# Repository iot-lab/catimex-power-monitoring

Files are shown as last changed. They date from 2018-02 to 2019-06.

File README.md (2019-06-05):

# Catimex: Hardware

Custom developer board for measure the power consumption of a load connected in either the USB connector or in the HOUT header connector.

## Overview
This folder contains the necessary files to replicate the custom board develop for catimex project. This board has the following features:
* [STM32F103RE Microcontroller](https://www.st.com/en/microcontrollers/stm32f103re.html)
* [FT2232H USB Bridge](https://www.ftdichip.com/Support/Documents/DataSheets/ICs/DS_FT2232H.pdf)
* [INA226 Power monitor](http://www.ti.com/product/INA226)

The board has two different power supply, one for the load (open-node) and other for the main microcontroller (control-node). In the picture below, the micro usb connector of the open node is marked in blue, while the connector for the control node is marked in a red rectangle.

In this version the jumper in 3V3 must be placed to power the control node.

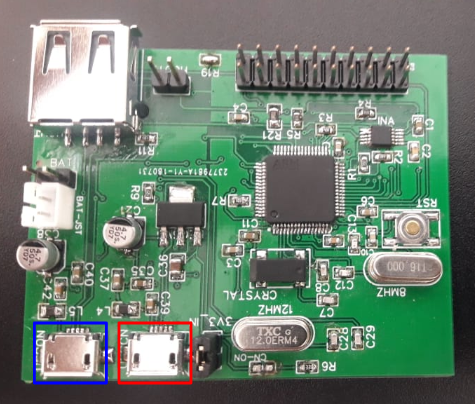
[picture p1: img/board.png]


## How to use

### Power the board
#### From a usb port
To measure the power consumption of any load, connect two micro usb ports to each connector. The control node will send the information through serial port so you need to connect this to a pc. On the other side you can power the open node from a pc usb port or any other source.

#### From an external source
If you do not want to connect the control node to a pc, you can connect a battery in the JST connector on the board and access to serial port through the pin headers exposed on the board.

### Connect the load
The load or open-node should be connected in the usb connector or in the HOUT header connector. Once plug in you should start to receive the measurement of bus voltage and current used by the board.

### Power Supply and Start-up Considerations
The board available connectors are:
* USBCN : USB connector for the control node. If connected the control node is power up and you will be able to receive through serial console.
* USBON : USB connector for power up and interact with any node connected, in this case the open node.
* USB : USB port to connect a external node, as in this case the open node
* HOUT : Header to power an external node (open node) from a header connector instead of using the USB port above.
* BAT : Header connector to plug any external battery for the open node, instead of use USBON connection.
* BAT-JST : JST connector to plug in an external battery
* 3V3_IN : Feed the control node from the on-board voltage regulator and USBCN. A jumper has to be connecting both pins in order to power the control node from USB port. Note: This was build for development purposes.

The pinout configuration is in the image below:

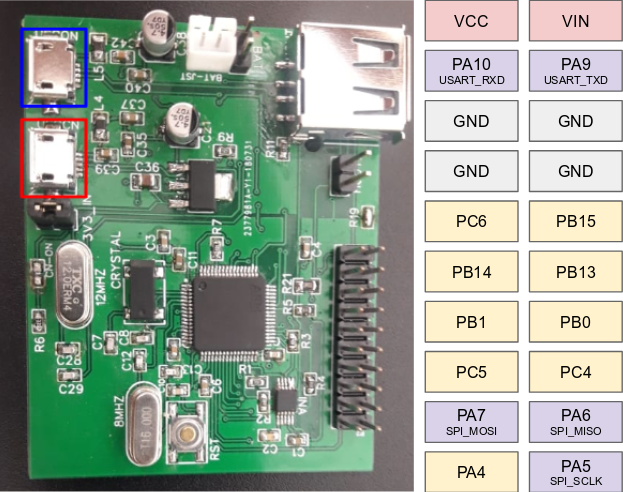
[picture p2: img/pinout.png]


## Need features
From the different test made, there are the following missing features:
* Add 2 LEDs to the board
* Add an OFF state for power the open node
* Match I2C port for INA226 with current in FIT IoTLab and the ALERT interrupt pin
* Add a battery charger
* Be able to put a 802.15.4 radio on top
* Expose same pins as the control node in FIT
* Be able to measure voltage of battery

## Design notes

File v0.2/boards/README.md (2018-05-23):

# PCB eagle for current measurement board

This folder contains the eagle files for v0.2 current measurement board. It contains two options for the circuit:

* LTC6102 based circuit measurement
* ADA4522 based circuit measurement

This version only contains the circuit for measure the current, does not have a mcu inside or any control for the usb hub. It has different pins and test pads to access and control the behavior of the board, as the calibration stage, the output of the stages, the power management among others.

## Input and Outputs
The inputs of this version of the board control different areas which can be access through:
 * Micro usb port
 * Pins for optional external power
 * Pin SW_PWR for selecting source of power for the target MCU
 * Pins SW0-SW4 to control calibration

The output depends of the specific version of the board, but in general terms it contains:
 * Pins to access to the measurement value
 * USB port to connect target MCU  

## How to Use
For use this board you need a external mcu that can read the adc value from the output and can control the different input of the system

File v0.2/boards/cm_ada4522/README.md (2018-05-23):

# Current measurement board based on ADA4522

This version of the measurement board uses an ADA4522 opamp. This opamp was chosen for its CMRR, Low voltage drift, low offset voltage and other characteristics for this application. It was used in an instrumentation amplifier configuration.

The circuit is divided in two types of currents ranges, the in amp configuration is design to measure the range 1uA - 1mA, the other one use the AD8422 precision instrumentation amplifier for the range 1mA-100mA.

### Rating
 * Low current range 1st stage gain x100
 * Low current range 2st stage gain x10
 * High current range gain x40

#### Input and Outputs
The inputs of board are:
 * Micro usb port
 * Pins for optional external power
 * Pin SW_PWR for selecting source of power for the target MCU
 * Pins SW0-SW4 to control calibration

The outputs:
 * Pins to access to both the measurement value: VoutL, VoutH, GND
 * USB port to connect target MCU  

#### Jumpers
Different jumpers are used in the board to select connect internal or external power to feed the IC.

#### Test Pads
At least three test pads were put in the board to can measure key values, as in the first stage output, output of power stages and output of regulation stage.

## Board versions
### ADA4522 v0
This version of the board is being develop and tested

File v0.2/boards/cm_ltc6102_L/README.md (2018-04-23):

# PCB eagle for LTC6102 based current measurement board

### Some notation
* current measuring board (CMB): the designed circuit that measure shunt voltage, and supply voltage.
* mcu: the microcontroller that is connect to the CMB, performs calibrations and converts the supply voltage and current measurements.
* node: the target mcu which pwoer consumption the CMB is measuring.

### How to use

* connect switch controllers (SW0 to SW4) to 5 different GPIO on any mcu.
* if you wan't to control what supply is used for the node connect SW_PWR
* connect the ADC_CM_LOW to and ADC pin on your mcu
* connect INA226 sda and scl to your mcu sda and scl pins, PU ressitors are supplied in this board
* alert pin of INA226 is supplied, not used by default
* power the CMB by either connecting it to it's microUSB port ore the 5V supply pin.
* bypass the targeted node power supply by either connecting it's power source to VEXT or the USB port on CMB.
* if the targeted node supply source is connected to VEXT then the node can be powered by connecting it's power input to VMCU. By default the mcu will be supplied from the USB. SW_CTRL_PWR allows the user to select which.

### Ratings:
- Power supply: 5V from USB or 5V from external supply
- First Low range stage gain x1000.
- Second Low range stage gain x11.
- Ina226 for High current range 82mA-250uA
- LTC6102 for Low current range 250ua-0.01uA

#### Input Output pins

Multiple input/output pins are supplied (There are PD resistors so calibration resistors and node supply are normally turned off). These are:

- SW_PWR: switch between VEXT and VUSB for supplying node.
- SW0: switch between calibration mode and suplying node.
- SW1-4: switches on or off calibration resistors.
- VMCU: output voltage that powers the targeted node it's short-circuited to the female type A USB.
- GND: ground
- ADC: low current value tu be read by mcu ADC
- SDA/SCL: I2C wire connection to read INA226 voltage and current values
- VEXT: external supply oint for node, eg: a battery
- +5V: 5V input/output depending on operation

#### Jumper

- A jumpers enables or not the use of the regulated 5V power supply, if not the filtered USB supply powers all the CMB IC's

#### Test Pads

Multiple test pads have been exposed for board testing

- 5V_F: filter 5V usb supply
- 5.5V: output of boost stage
- 5VR: 5 vols LDO output
- Vin: voltage that comes in to 4-terminal shunt current in pad
- Vout: voltage that comes out of 4-terminal shunt current out pad
- SHUNT+: voltage that comes form 4-terminal shunt voltage+ read pad
- SHUNT-: voltage that comes form 4-terminal shunt voltage- read pad

#### Leds

The board has 6 status Leds:

- MCU_VUSB_LED: indicates if node is supplied from USB
- MCU_EXT_LED: indicates if node is supplied from external supply
- VCALID_LED: indicates if in calibration mode
- VMCU_LED: indicates if in normal mode
- USB_LED: if usb is connected
- 5V_LED: if regultor is on

# Board versions

## LTC6102 v0

### Details

Analog and digital ground are joined in star way.

USB supply is filterd threw a ferrite, every precisión IC is also isolated threw a ferrite.

USB enclosure is connected to the digital ground.

### Prototyping and testing conclusion

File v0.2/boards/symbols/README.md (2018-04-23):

## This folder contains all eagle symbols used in the board.

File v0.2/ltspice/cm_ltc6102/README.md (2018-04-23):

# Spice models for power measurement boards
These spice models were used to simulate the behavior of the circuits before prototyping them. 

## About files
### cm_ad4522_A.asc
Simulates a ADA4522 based circuit. Three of them are connectd as an INA and a forth as a Salen Key filter. Was not prototyped.

### cm_ltc6102
Simulates a LTC6102 based circuit. Uses LTC6102 as first stage, it is operating out of data sheet range but still with inputs as low as 2.7V. It has a gain of x1000.

#### A v/s B
A v/s B version changes the type of low pass filter used at the output. In one case it's Salen Key 2nd order (A) and in the other a simple RC filter (B).

#### tlv272 v/S ADA4528
This deffines two ways of implementing the second gain stage and sallen-key filter (when there is one)
. Both have similar operations at different costs.

### v3_max4239_lt624X.asc
This schematic was used to simulated and verify the sallen key designed cut-off frequency and operation.

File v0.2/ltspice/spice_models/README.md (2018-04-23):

## SPICE MODELS

This folder contains spice models for the IC used in the Ltspice schematics.

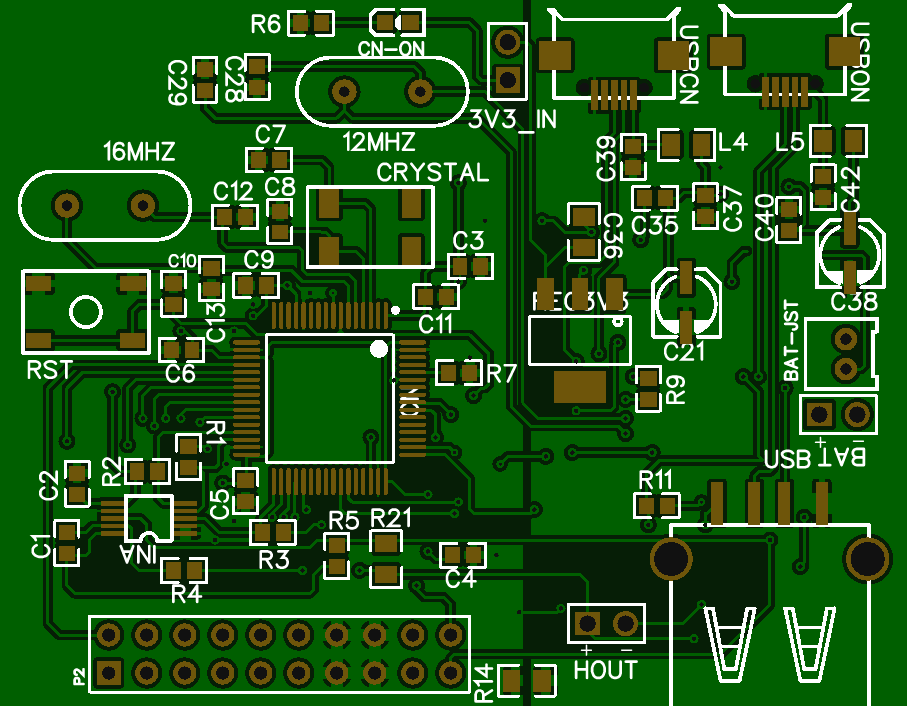
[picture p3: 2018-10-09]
Layout/top.png

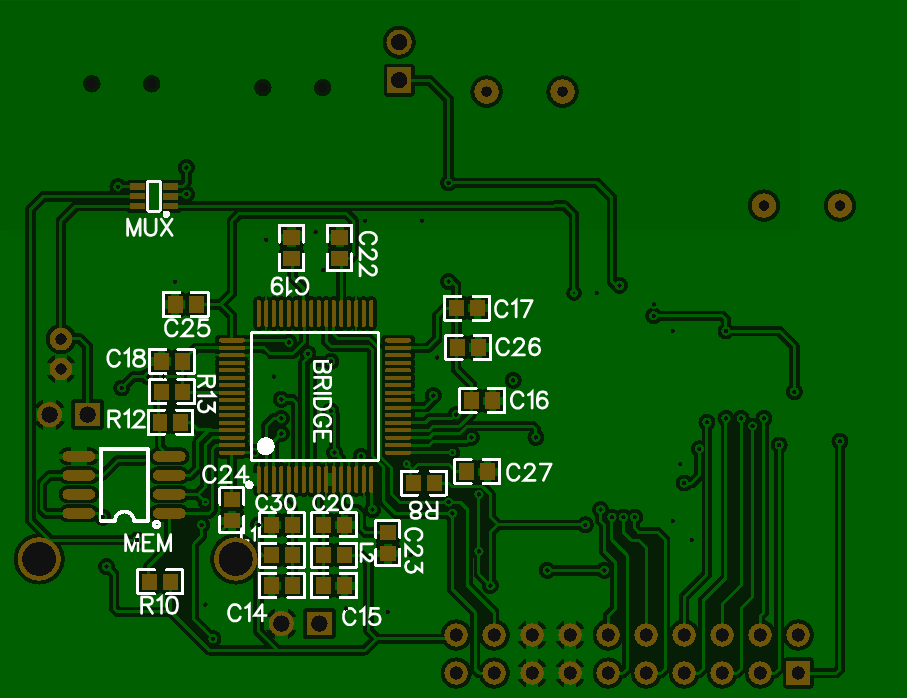
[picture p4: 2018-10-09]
Layout/bottom.png

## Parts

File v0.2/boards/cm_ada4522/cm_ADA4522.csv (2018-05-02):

Index | Quantity | Part Number | Description | Customer Reference | Available Quantity | Backorder Quantity | Unit Price USD | Extended Price USD
1 | 1 | RG16N100WCT-ND | RES SMD 100 OHM 0.05% 1/10W 0603 |  | 1 | 0 | 0.92 | 0.92
2 | 5 | TNP100KAACT-ND | RES 100K OHM 0.1% 1/8W 0603 |  | 5 | 0 | 0.462 | 2.31
3 | 2 | RG16N510WCT-ND | RES SMD 510 OHM 0.05% 1/10W 0603 |  | 2 | 0 | 0.92 | 1.84
4 | 2 | RG16N20.0KWCT-ND | RES SMD 20K OHM 0.05% 1/10W 0603 |  | 2 | 0 | 0.92 | 1.84
5 | 2 | RG16P200BCT-ND | RES SMD 200 OHM 0.1% 1/10W 0603 |  | 2 | 0 | 0.41 | 0.82
6 | 1 | AD8422BRMZ-ND | IC OPAMP INSTR 2.2MHZ RRO 8MSOP |  | 1 | 0 | 8.68 | 8.68
7 | 1 | ADM7170ACPZ-3.0-R7CT-ND | IC REG LINEAR 3V 500MA 8LFCSP |  | 1 | 0 | 2.7 | 2.7
8 | 1 | LT8582EDKD#PBF-ND | IC REG MULT CONFIG INV ADJ 24DFN |  | 1 | 0 | 8.18 | 8.18
9 | 1 | 576-3967-1-ND | IC REG BOOST ADJ 0.9A SOT23-5 |  | 1 | 0 | 0.73 | 0.73
10 | 3 | 497-5561-1-ND | DIODE SCHOTTKY 40V 300MA SOD523 |  | 3 | 0 | 0.36 | 1.08
11 | 2 | 160-1447-6-ND | LED RED CLEAR 0603 SMD |  | 2 | 0 | 3.79 | 7.58
12 | 2 | 160-1446-6-ND | LED GREEN CLEAR 0603 SMD |  | 2 | 0 | 3.79 | 7.58
13 | 2 | P12KDBCT-ND | RES SMD 12K OHM 0.1% 1/10W 0603 |  | 2 | 0 | 0.35 | 0.7
14 | 1 | P143KDBCT-ND | RES SMD 143K OHM 0.1% 1/10W 0603 |  | 1 | 0 | 0.35 | 0.35
15 | 1 | P130KDBCT-ND | RES SMD 130K OHM 0.1% 1/10W 0603 |  | 1 | 0 | 0.35 | 0.35
16 | 1 | Y1606-1.0B-ND | RES SMD 1 OHM 1W 2516 WIDE |  | 1 | 0 | 16.56 | 16.56
17 | 2 | A103067CT-ND | RES SMD 22 OHM 0.1% 1/16W 0603 |  | 2 | 0 | 0.55 | 1.1
18 | 1 | P2.0KDBCT-ND | RES SMD 2K OHM 0.1% 1/10W 0603 |  | 1 | 0 | 0.35 | 0.35
19 | 1 | P10KDBCT-ND | RES SMD 10K OHM 0.1% 1/10W 0603 |  | 1 | 0 | 0.35 | 0.35
20 | 1 | P30KDBCT-ND | RES SMD 30K OHM 0.1% 1/10W 0603 |  | 1 | 0 | 0.35 | 0.35
21 | 2 | P53.6KDBCT-ND | RES SMD 53.6KOHM 0.1% 1/10W 0603 |  | 2 | 0 | 0.35 | 0.7
22 | 1 | P6.04KDBCT-ND | RES SMD 6.04KOHM 0.1% 1/10W 0603 |  | 1 | 0 | 0.35 | 0.35
23 | 1 | A102234CT-ND | RES SMD 1M OHM 0.1% 1/16W 0603 |  | 1 | 0 | 0.44 | 0.44
24 | 1 | 541-10MAYCT-ND | RES SMD 10M OHM 0.5% 1/10W 0603 |  | 0 | 1 | 0.31 | 0.31
25 | 2 | 490-4780-1-ND | CAP CER 1000PF 100V X7R 0603 |  | 2 | 0 | 0.1 | 0.2
26 | 2 | 490-1458-1-ND | CAP CER 2000PF 50V C0G/NP0 0603 |  | 2 | 0 | 0.17 | 0.34
27 | 1 | 490-4781-1-ND | CAP CER 10000PF 100V X7R 0603 |  | 1 | 0 | 0.1 | 0.1
28 | 5 | 445-9871-1-ND | CAP CER 0.1UF 25V X8R 0603 |  | 5 | 0 | 0.28 | 1.4
29 | 2 | 587-4958-1-ND | CAP CER 1UF 50V X5R 0603 |  | 2 | 0 | 0.3 | 0.6
30 | 5 | 445-9015-1-ND | CAP CER 10UF 25V X5R 0603 |  | 0 | 5 | 0.96 | 4.8
31 | 5 | 1276-1900-1-ND | CAP CER 4.7UF 25V X5R 0603 |  | 5 | 0 | 0.43 | 2.15
32 | 2 | 1276-1878-1-ND | CAP CER 2.2UF 25V X5R 0603 |  | 2 | 0 | 0.29 | 0.58
33 | 1 | 296-19265-1-ND | IC SWITCH SPDT SOT23-6 |  | 1 | 0 | 0.88 | 0.88
34 | 1 | 296-19804-1-ND | IC SWITCH SPDT SC70-6 |  | 1 | 0 | 0.61 | 0.61
35 | 1 | 296-17906-1-ND | IC SWITCH DUAL SPST US8 |  | 1 | 0 | 0.84 | 0.84
36 | 1 | NDS8434CT-ND | MOSFET P-CH 20V 6.5A 8-SOIC |  | 1 | 0 | 1.82 | 1.82
37 | 5 | 732-2956-1-ND | FIXED IND 4.7UH 1A 160 MOHM SMD |  | 5 | 0 | 0.81 | 4.05
38 | 1 | 609-4618-1-ND | CONN USB MICRO B RECPT SMT R/A |  | 1 | 0 | 0.42 | 0.42
39 | 1 | ADA4522-4ARUZ-ND | IC OPAMP 55V LN ZD 14TSSOP |  | 1 | 0 | 8.53 | 8.53
40 | 8 | YAG1237CT-ND | RES SMD 1K OHM 0.1% 1/10W 0603 |  | 8 | 0 | 0.34 | 2.72
41 | 1 | 490-1058-1-ND | FERRITE BEAD 60 OHM 1806 1LN |  | 1 | 0 | 0.32 | 0.32
42 | 10 | 1276-3486-1-ND | RES 100K OHM 1% 1/8W 0603 |  |  |  | 0.1 | 0.33

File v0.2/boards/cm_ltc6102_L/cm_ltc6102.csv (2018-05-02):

Index | Quantity | Part Number | Description | Customer Reference | Available Quantity | Backorder Quantity | Unit Price USD | Extended Price USD
1 | 5 | RNCF0603TKY10K0CT-ND | RES 10K OHM 0.01% 1/10W 0603 |  | 5 | 0 | 2.15000 | 10.75
2 | 1 | ADA4528-2ARMZ-R7CT-ND | IC OPAMP ZERO-DRIFT 3.4MHZ 8MSOP |  | 1 | 0 | 4.74000 | 4.74
3 | 2 | A124686CT-ND | RES SMD 9.09 OHM 0.1% 1/16W 0603 |  | 2 | 0 | 0.78000 | 1.56
4 | 1 | RNCF0805TKY1K00CT-ND | RES 1K OHM 0.01% 1/8W 0805 |  | 1 | 0 | 2.15000 | 2.15
5 | 1 | Y1607-1.00-ND | RES SMD 1 OHM 1/2W 2516 WIDE |  | 1 | 0 | 12.30000 | 12.30
6 | 1 | 490-12558-1-ND | CAP CER 0.1UF 16V X7R 0805 |  | 1 | 0 | 0.12000 | 0.12
7 | 2 | RNCF0603AKT10R0CT-ND | RES 10 OHM 0.05% 1/10W 0603 |  | 2 | 0 | 0.97000 | 1.94
8 | 1 | A103123CT-ND | RES SMD 6.2K OHM 0.1% 1/16W 0603 |  | 1 | 0 | 0.68000 | 0.68
9 | 1 | 399-13711-1-ND | CAP CER 0603 10PF 50V X7R 10% AU |  | 1 | 0 | 0.26000 | 0.26
10 | 3 | 490-1047-1-ND | FERRITE BEAD 1 KOHM 0805 1LN |  | 3 | 0 | 0.17000 | 0.51
11 | 5 | 490-1543-1-ND | CAP CER 1UF 10V X5R 0603 |  | 5 | 0 | 0.12000 | 0.60
12 | 1 | 490-1058-1-ND | FERRITE BEAD 60 OHM 1806 1LN |  | 1 | 0 | 0.32000 | 0.32
13 | 1 | ADM7170ACPZ-5.0-R7CT-ND | IC REG LINEAR 500MA 8LFCSP |  | 0 | 1 | 2.70000 | 2.70
14 | 3 | 490-6065-1-ND | CAP CER 4.7UF 16V X7R 1206 |  | 0 | 3 | 0.58000 | 1.74
15 | 1 | 576-3967-1-ND | IC REG BOOST ADJ 0.9A SOT23-5 |  | 1 | 0 | 0.73000 | 0.73
16 | 1 | 490-11996-1-ND | CAP CER 2.2UF 10V X7R 0603 |  | 1 | 0 | 0.45000 | 0.45
17 | 1 | 497-5561-1-ND | DIODE SCHOTTKY 40V 300MA SOD523 |  | 1 | 0 | 0.36000 | 0.36
18 | 2 | 490-4774-1-ND | CAP CER 0.1UF 16V X7R 0603 |  | 0 | 2 | 0.10000 | 0.20
19 | 1 | 296-19265-1-ND | IC SWITCH SPDT SOT23-6 |  | 1 | 0 | 0.88000 | 0.88
20 | 4 | MCT0603-10.0K-CFCT-ND | RES SMD 10K OHM 1% 1/8W 0603 |  | 4 | 0 | 0.18000 | 0.72
21 | 1 | 311-1.00MHRCT-ND | RES SMD 1M OHM 1% 1/10W 0603 |  | 1 | 0 | 0.10000 | 0.10
22 | 1 | MCT0603-10.0M-CFCT-ND | RES SMD 10M OHM 1% 1/8W 0603 |  | 1 | 0 | 0.27000 | 0.27
23 | 1 | 160-1447-1-ND | LED RED CLEAR 0603 SMD |  | 1 | 0 | 0.29000 | 0.29
24 | 1 | 160-1446-1-ND | LED GREEN CLEAR 0603 SMD |  | 1 | 0 | 0.29000 | 0.29
25 | 2 | 160-1445-1-ND | LED ORANGE CLEAR 0603 SMD |  | 2 | 0 | 0.27000 | 0.54
26 | 1 | 609-4618-1-ND | CONN USB MICRO B RECPT SMT R/A |  | 1 | 0 | 0.42000 | 0.42
27 | 1 | 296-19804-1-ND | IC SWITCH SPDT SC70-6 |  | 1 | 0 | 0.61000 | 0.61
28 | 1 | 490-10563-1-ND | FIXED IND 10UH 1A 460 MOHM SMD |  | 1 | 0 | 0.22000 | 0.22
29 | 1 | 160-1448-1-ND | LED YELLOW CLEAR 0603 SMD |  | 1 | 0 | 0.31000 | 0.31
30 | 2 | 296-17906-1-ND | IC SWITCH DUAL SPST US8 |  | 2 | 0 | 0.84000 | 1.68
31 | 1 | 296-29034-1-ND | IC MONITOR PWR/CURR BIDIR 10MSOP |  | 1 | 0 | 2.88000 | 2.88
32 | 7 | 490-1494-1-ND | CAP CER 1000PF 50V X7R 0603 |  | 7 | 0 | 0.10000 | 0.70
33 | 6 | 311-1.00KHRCT-ND | RES SMD 1K OHM 1% 1/10W 0603 |  | 6 | 0 | 0.10000 | 0.60
34 | 8 | 311-100KHRCT-ND | RES SMD 100K OHM 1% 1/10W 0603 |  | 8 | 0 | 0.10000 | 0.80
35 | 1 | P100KBSCT-ND | RES SMD 100K OHM 0.05% 1/8W 0805 |  | 1 | 0 | 0.79000 | 0.79
36 | 3 | 541-3956-1-ND | RES SMD 1 OHM 1% 1/10W 0603 |  | 3 | 0 | 0.10000 | 0.30
37 | 1 | 541-0.0SBCT-ND | RES SMD 0 OHM JUMPER 1/4W 0603 |  | 1 | 0 | 0.17000 | 0.17
38 | 1 | 490-4781-1-ND | CAP CER 10000PF 100V X7R 0603 |  | 1 | 0 | 0.10000 | 0.10
39 | 1 | P29.4KDACT-ND | RES SMD 29.4K OHM 0.1% 1/8W 0805 |  | 1 | 0 | 0.36000 | 0.36
40 | 2 | 490-12380-1-ND | CAP CER 10UF 16V X5R 0805 |  | 2 | 0 | 0.34000 | 0.68
41 | 1 | LTC6102IMS8#PBF-ND | IC OPAMP CURR SENSE 200KHZ 8MSOP |  | 1 | 0 | 4.07000 | 4.07

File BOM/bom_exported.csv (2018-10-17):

ID | Name | Designator | Footprint | Quantity | Manufacturer Part | Manufacturer | Supplier | Supplier Part | Price | Mounted | LCSC Assembly
1 | INA226AIDGSR | INA | MSOP-10 | 1 | INA226AIDGSR | TI | Digi-Key | 296-29034-1-ND |  | Yes
2 | 3.3k 5% | R1,R2 | 0603 | 2 | ? |  | Digi-Key | 311-3.3KGRCT-ND |  | Yes
3 | 100k 5% | R3 | 0603 | 1 | ? |  | Digi-Key | P100KGCT-ND |  | Yes
4 | 10 1% | R4,R5 | 0603 | 2 | ? |  | Digi-Key | MCT0603-1.00-CFCT-ND |  | Yes
5 | 100n | C1,C2,C14,C15,C16,C17,C18,C19,C22,C23,C24,C26,C27,C3,C4,C5,C6,C10,C37,C40 | 0603 | 20 | ? |  | Digi-Key | 399-1099-1-ND |  | Yes
6 | 1 0.25% | R21 | 0805 | 1 | ? |  | Digi-Key | CRT0805-CY-1R00ELFCT-ND |  | Yes
7 | FT2232HL | BRIDGE | LQFP-64_10X10X05P | 1 | FT2232HL | FTDI | Digi-Key | 768-1024-1-ND |  | Yes
8 | 600R/0.5A | L1,L2 | 0603 | 2 | 742863160 |  | Digi-Key | 732-2389-1-ND |  | Yes
9 | 1u | C25,C11 | 0603 | 2 | ? |  | Digi-Key | 1276-1182-1-ND |  | Yes
10 | 10k | R8,R10,R11,R13,R7 | 0603 | 5 | ? |  | Digi-Key | P10KGCT-ND |  | Yes
11 | 12k | R9 | 0603 | 1 | ? |  | Digi-Key | P12KGCT-ND |  | Yes
12 | CRYSTAL | 12MHZ | HC49US | 1 | 9B-12.000MEEJ-B |  | Digi-Key | 887-1238-ND |  | No
13 | 27p | C28,C29 | 0603 | 2 | ? |  | Digi-Key | 490-6047-1-ND |  | Yes
14 | AT93C66B-SSHM-T | MEM | SOIC-8_150MIL | 1 | AT93C66B-SSHM-T | MICROCHIP | Digi-Key | AT93C66B-SSHM-TCT-ND |  | Yes
15 | 2.2k | R12 | 0603 | 1 | ? |  | Digi-Key | P2.2KGCT-ND |  | Yes
16 | 4.7u | C30,C20 | 0603 | 2 | ? |  | Digi-Key | 1276-1045-1-ND |  | Yes
17 | STM32F103RET6 | CN | LQFP-64_10X10X05P | 1 | STM32F103RET6 | STMicroelectronics | Digi-Key | 497-11529-ND |  | Yes | Yes
18 | ABS25 - Crystal 32.768kHz SMD | CRYSTAL | ABS25 - SMD CRYSTAL 32.768KHZ | 1 | ABS25-32.768KHZ-6-T |  | Digi-Key | 535-10240-1-ND |  | Yes
19 | 8p | C7,C8 | 0603 | 2 | ? |  | Digi-Key | 490-14433-1-ND |  | Yes
20 | 10n | C9,C39,C42 | 0603 | 3 | ? |  | Digi-Key | 445-5662-1-ND |  | Yes
21 | CRYSTAL | 16MHZ | HC49US | 1 | ABL-8.000MHZ-B2 |  | Digi-Key | 535-9041-ND |  | No
22 | 20p | C12,C13 | 0603 | 2 | ? |  | Digi-Key | 399-14498-1-ND |  | Yes
23 | FSMCTTR | RST | FSMCTTR | 1 | FSMCTTR |  | Digi-Key | 450-2133-1-ND |  | Yes
24 | LM3940IMP-3.3 | REG3V3 | SOT223 | 1 | ? |  | Digi-Key | LM3940IMPX-3.3/NOPBCT-ND |  | Yes
25 | 0.47u | C35 | 0603 | 1 | ? |  | Digi-Key | 490-1539-1-ND |  | Yes
26 | 60[OHM] | L4,L5 | 0805 | 2 | ? |  | Digi-Key | 535-13420-1-ND |  | Yes
27 | LED-Red(0603) | CN-ON | LED-0603 | 1 | FC-DA1608UGK-520D10 | Foshan NationStar Optoelectronics | Digi-Key | 160-1446-6-ND |  | Yes
28 | 330 | R6 | 0603 | 1 | ? |  | Digi-Key | YAG1314CT-ND |  | Yes
29 | Header-Male-2.54_1x2 | 3V3_IN,BAT,HOUT | HDR-2X1/2.54 | 3 | 826629-2 | TE Connectivity | Digi-Key | 732-5315-ND |  | Yes
30 | 4.7u | C21,C38 | CAP-D4.0XH5.5 | 2 | ? |  | Digi-Key | PCE3931CT-ND |  | Yes
31 | 33u | C36 | 0805 | 1 | ? |  | Digi-Key | 445-5986-1-ND |  | Yes
32 | TS5A4624DCKT | MUX | SC-70-6(SOT-363) | 1 | TS5A4624DCKT | TI | Digi-Key | 296-19804-1-ND |  | Yes
33 | 0 | R14 | 0805 | 1 | ? |  | Digi-Key | 311-0.0CRCT-ND |  | Yes
34 | Micro USB-B 5P_C40942 | USBCN,USBON | MICRO-USB-12 | 2 | Micro USB-B 5P_C40942 | ValuePro | Digi-Key | 609-4052-1-ND |  | Yes
35 | B2B-PH-K-S(LF)(SN) | BAT-JST | PH-2A | 1 | B2B-PH-K-S(LF)(SN) | JST | Digi-Key | 455-1704-ND |  | Yes
36 | Header-Male-2.54_2x10 | P2 | HDR-10X2/2.54 | 1 | ? |  | Digi-Key | 609-3221-ND |  | Yes
37 | CONN-USB-Female | USB | CONN-USB-A | 1 | 1001-002-01100 |  | Digi-Key | 1175-1001-ND |  | Yes

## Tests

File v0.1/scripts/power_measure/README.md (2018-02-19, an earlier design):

# Power measurement Scripts

This folder contains resources to control the measuring node and register different current measurements. The files contained here are:

* **master.py**: initial non working python script to read from node.

* **serial_ports.py**: python script that controls the measure_node. It opens a serial terminal, reads/receives calibration values from the node, and proceeds to specify sampling rate for the node. Measured values (ADC voltage readings) are transformed to current  values and printed in terminal.

* **measure_node**: contains c code based on RIOT to flash on node. It's assumes that RIOT is in the same directory as this repo.

## Future work

As of now serial_ports.py just captures serial data but isn't logging it anywhere. This should be interfaced/adapted to work with FIT IoT-Lab code or other. Proper testing should be done, some parts of the code should be subprocesses. General cleanup.

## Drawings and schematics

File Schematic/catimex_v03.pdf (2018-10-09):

## VCC

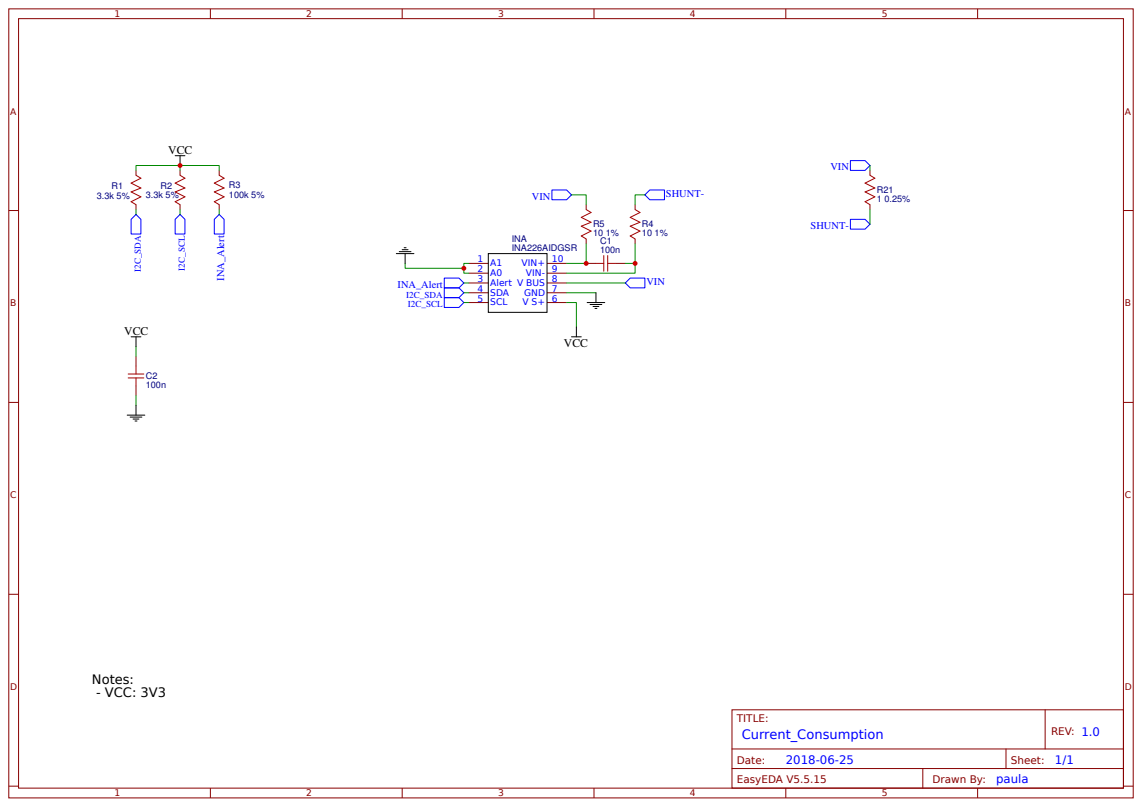
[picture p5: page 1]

## VCC

## VCC

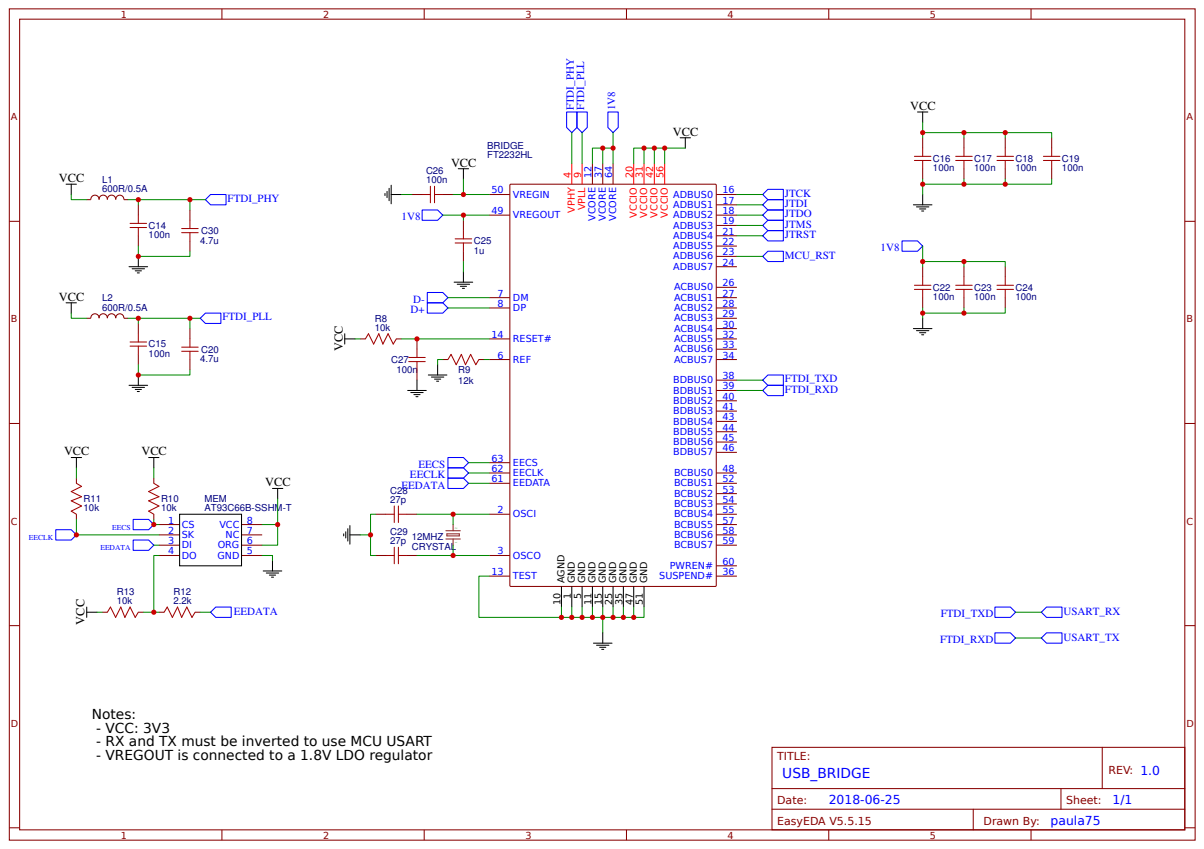
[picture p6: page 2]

Notes:
- VCC: 3V3
- RX and TX must be inverted to use MCU USART
- VREGOUT is connected to a 1.8V LDO regulator

## VCC

## VCC

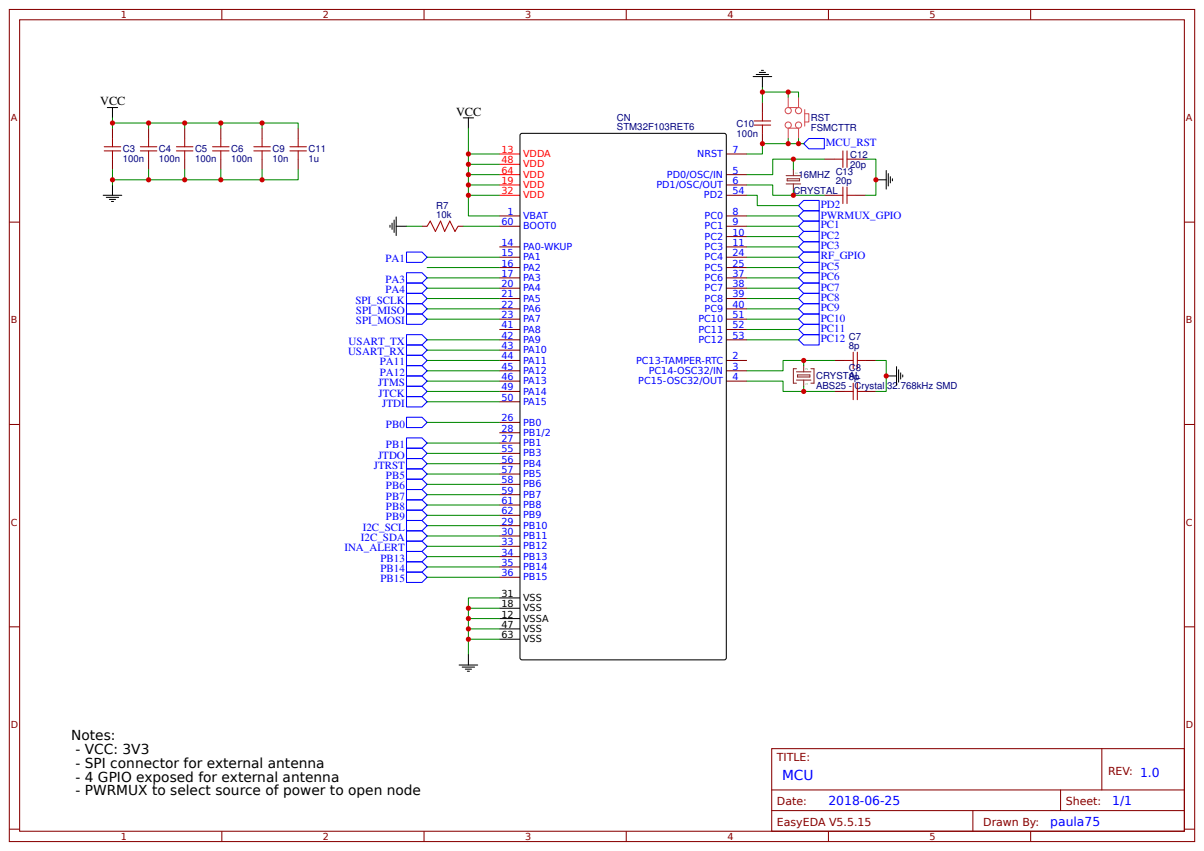
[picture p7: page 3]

Notes:
- VCC: 3V3
- SPI connector for external antenna
- 4 GPIO exposed for external antenna
- PWRMUX to select source of power to open node

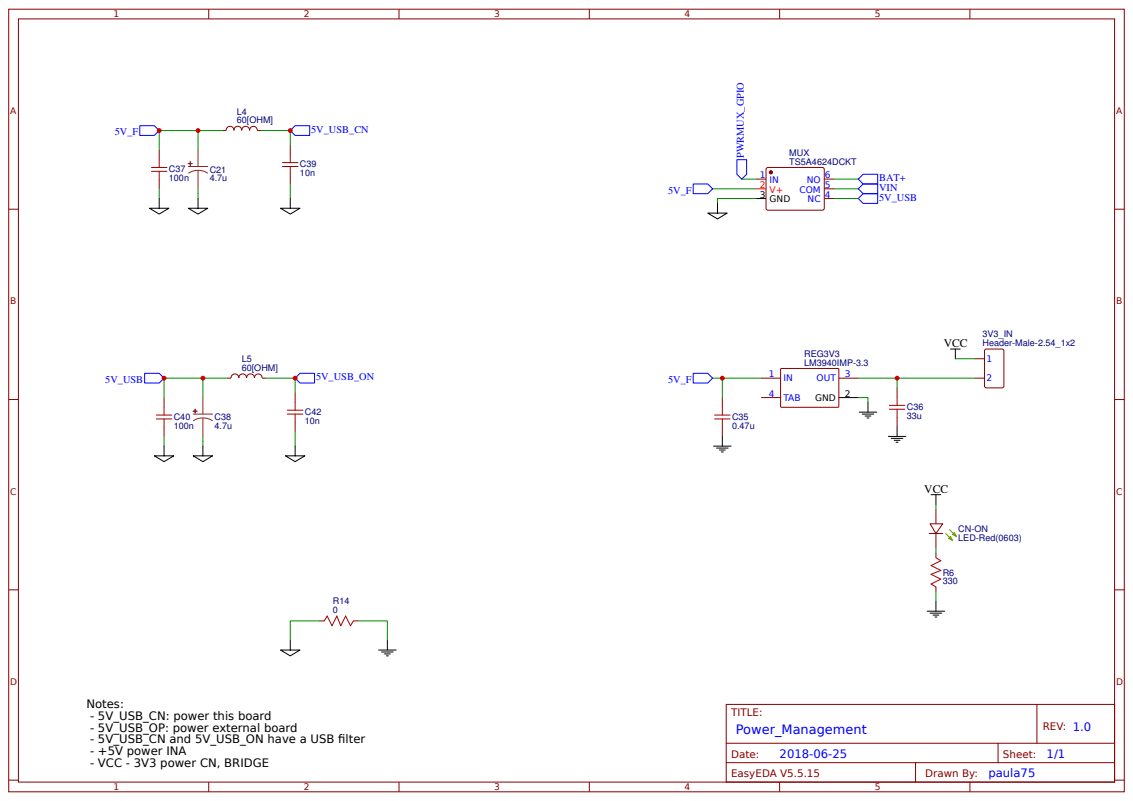
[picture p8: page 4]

Notes:
- 5V_USB_CN: power this board
- 5V_USB_OP: power external board
- 5V_USB_CN and 5V_USB_ON have a USB filter
- +5V power INA
- VCC - 3V3 power CN, BRIDGE

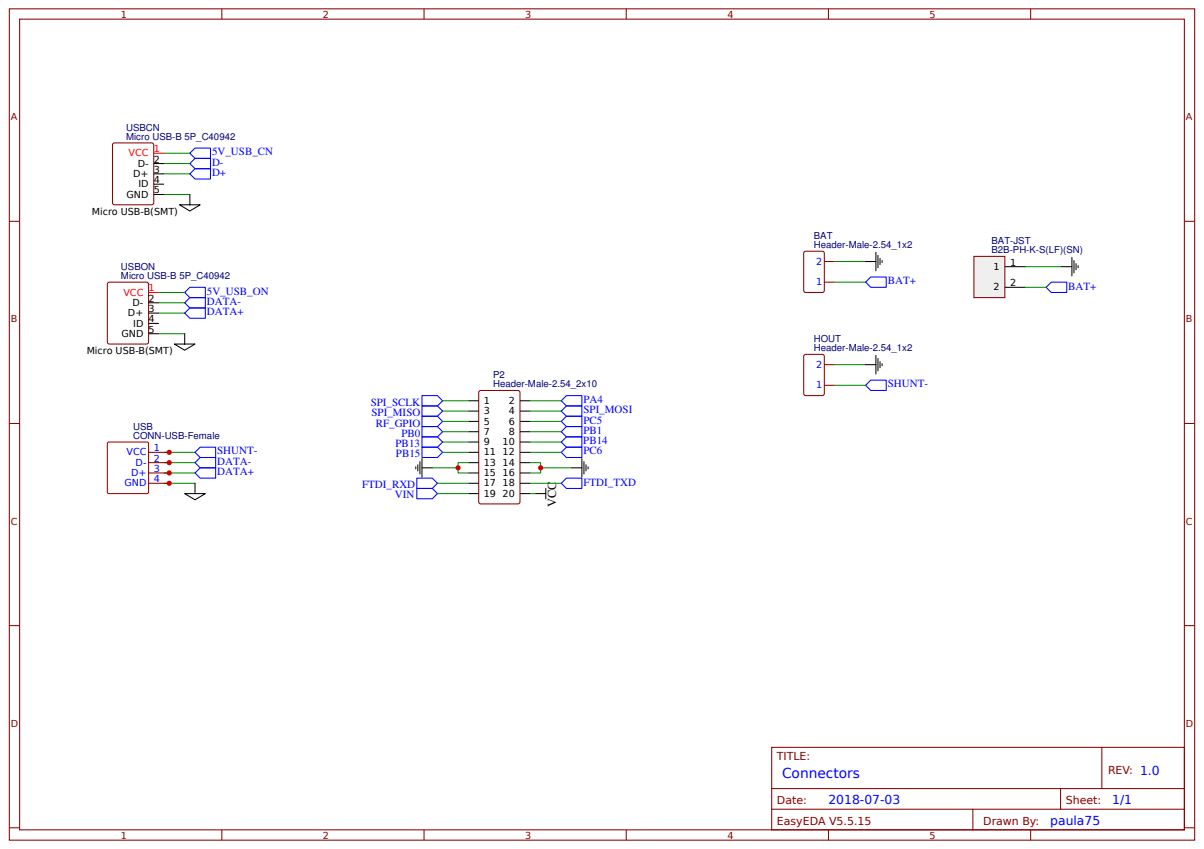
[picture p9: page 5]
TITLE:; Connectors; REV: 1.0; Date:; Sheet: 1/1; SHUNT- DATA- DATA+; Header-Male-2.54_1x2; BAT; BAT+ BAT+; 5V_USB_CN D- D+; 5V_USB_ON DATA- DATA+; SPI_SCLK; SPI_MISO; SPI_MOSI; RF_GPIO; HOUT; SHUNT-; Micro USB-B 5P_C40942; USBCN; VCC 1 D- 2 D+ 3 ID 4 GND 5; USBON; BAT-JST; VIN; Header-Male-2.54_2x10; VCC; FTDI_RXD; FTDI_TXD; CONN-USB-Female; USB; VCC 1 D- 2 D+ 3 GND 4

Micro USB-B(SMT)

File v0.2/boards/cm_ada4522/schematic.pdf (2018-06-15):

A

A

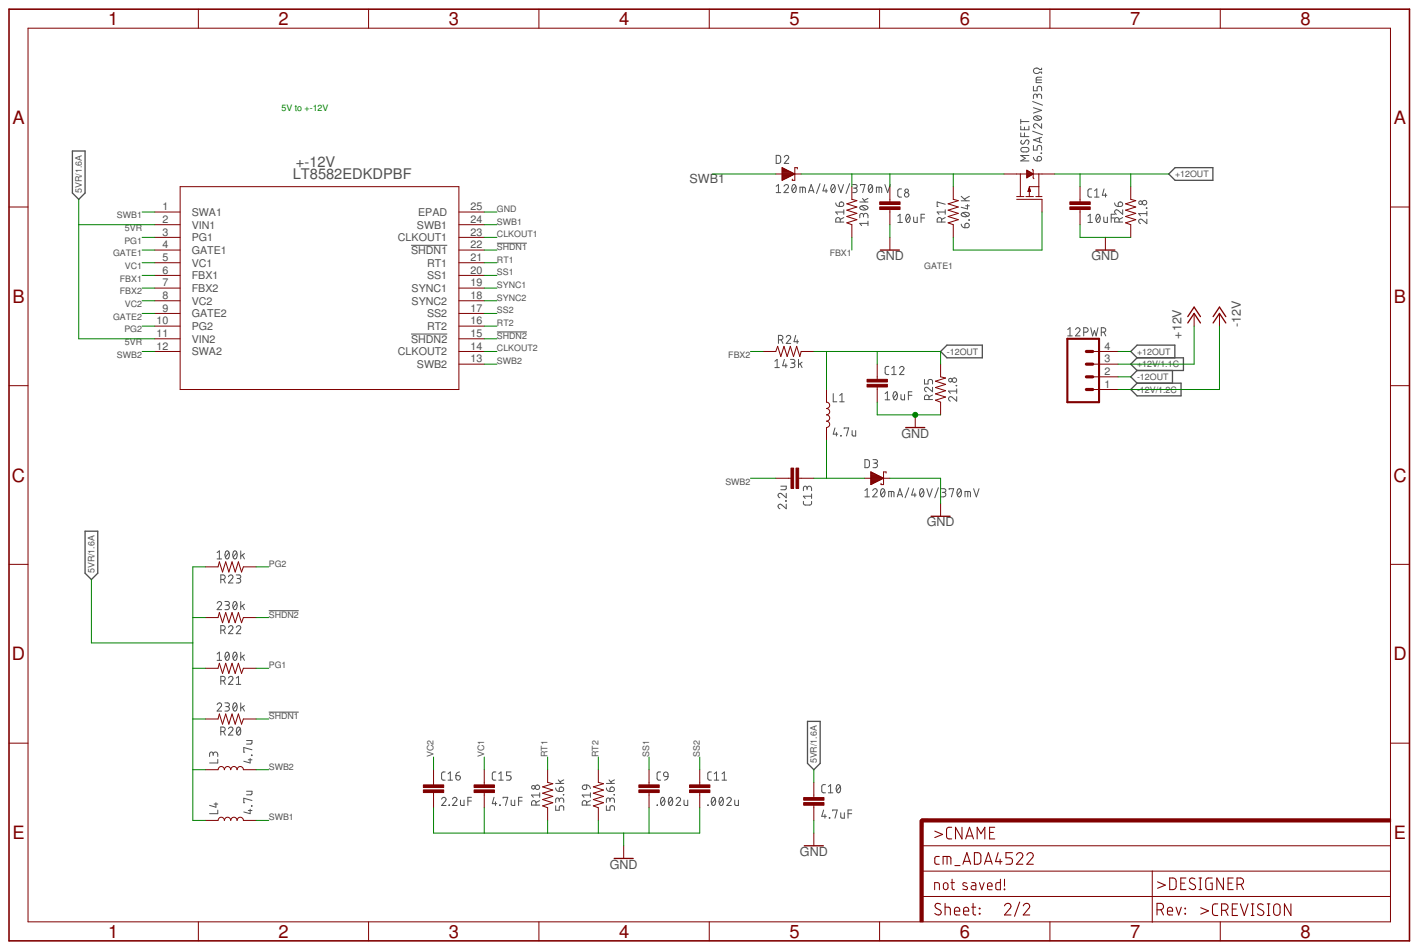
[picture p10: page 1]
LT8582EDKDPBF; GND GND; GND; SWA1; VIN1; GATE1; FBX1; FBX2; GATE2; VIN2; SWA2; SWB2; 13 CLKOUT2; 14 SHDN2; 17 SYNC2; 18 SYNC1; 21 SHDN1; 22 CLKOUT1; 23 SWB1; 24 EPAD; SWB1; SWB1 SWB1; VC1 FBX1; FBX1 FBX2; CLKOUT1 SHDN1; SHDN1; SYNC1 SYNC2 SS2; SHDN2; CLKOUT2 SWB2; -12OUT; +12OUT

A

A

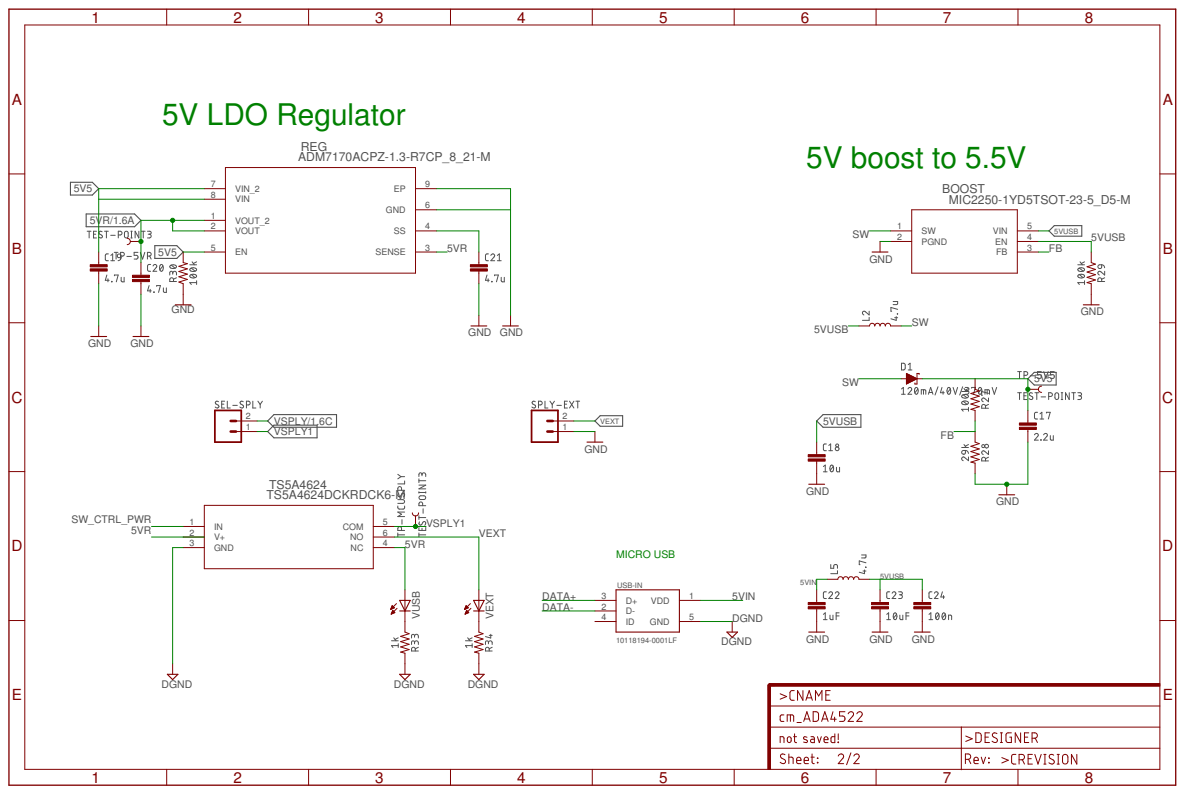
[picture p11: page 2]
MIC2250-1YD5TSOT-23-5_D5-M; ADM7170ACPZ-1.3-R7CP_8_21-M; GND; GND GND GND; GND TS5A4624DCKRDCK6-M; DGND; PGND; 4 VIN; 5 VIN_2; BOOST; VIN; VOUT_2; VOUT; SENSE; 4 GND; 9 REG; VUSB; VEXT; 4 COM; USB-IN D+; 5 VDD; SW_CTRL_PWR; 5VUSB; VSPLY1; VSPLY1 VSPLY/1.6C; 5VIN 5VIN; DATA- DATA+; 5V boost to 5.5V; 5V LDO Regulator; MICRO USB

A

1 | 2 | 3 | 4 | 5 | 6

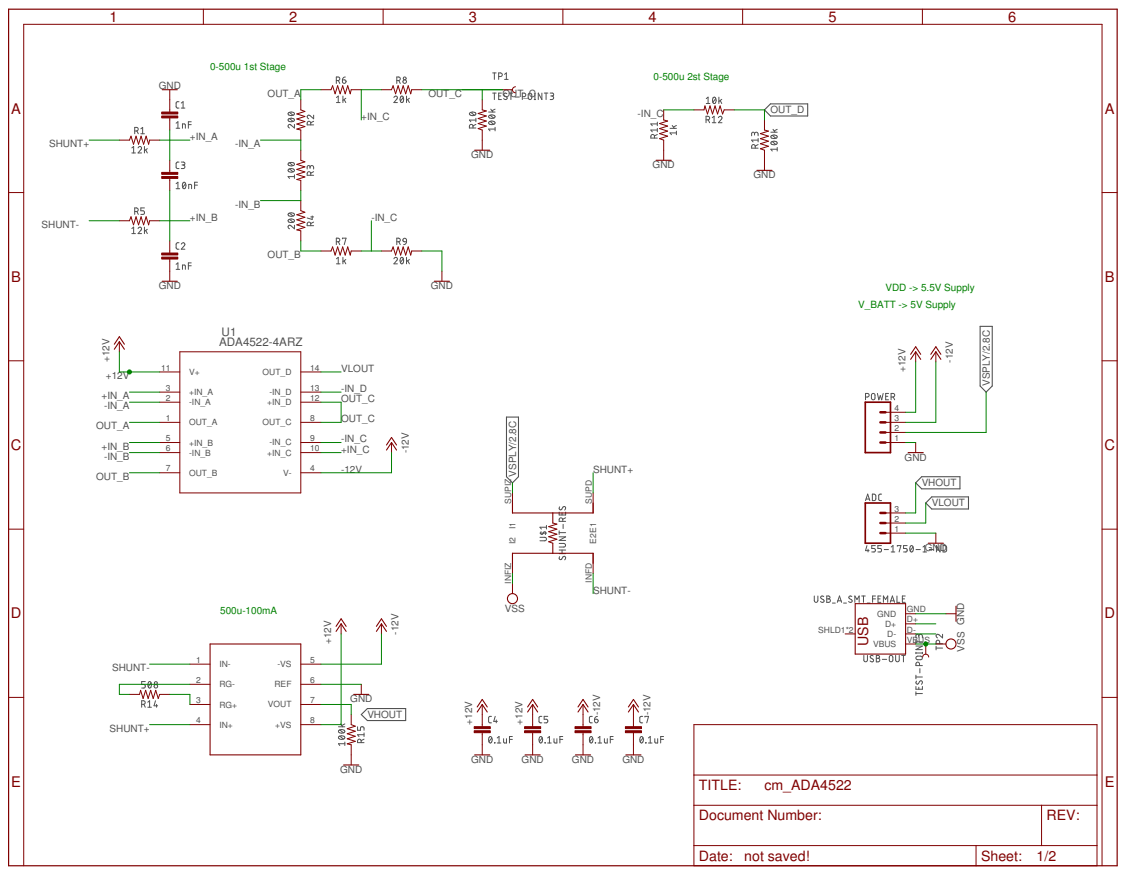
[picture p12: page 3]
GND; GND GND; VSS; VSS GND; ADA4522-4ARZ; 5 REF; I1 SUPIZ; E1 SUPD; INFIZ; INFD; D- VBUS; VBUS GND; SHLD1*2; OUT_A; OUT_B; 9 OUT_C; 13 OUT_D; VLOUT; VHOUT; VSPLY/2.8C; SHUNT+; SHUNT- SHUNT-; SHUNT-; OUT_D; -IN_D OUT_C OUT_C; OUT_C; USB; 0-500u 2st Stage

GND | 0-500u 1st Stage

VDD -> 5.5V Supply V_BATT -> 5V Supply

6 VOUT
7 +VS 8 | VHOUT

REV: TITLE: Document Number: cm_ADA4522

Date: not saved! | Sheet: 1/2

## 8 TS5A23166_1

A

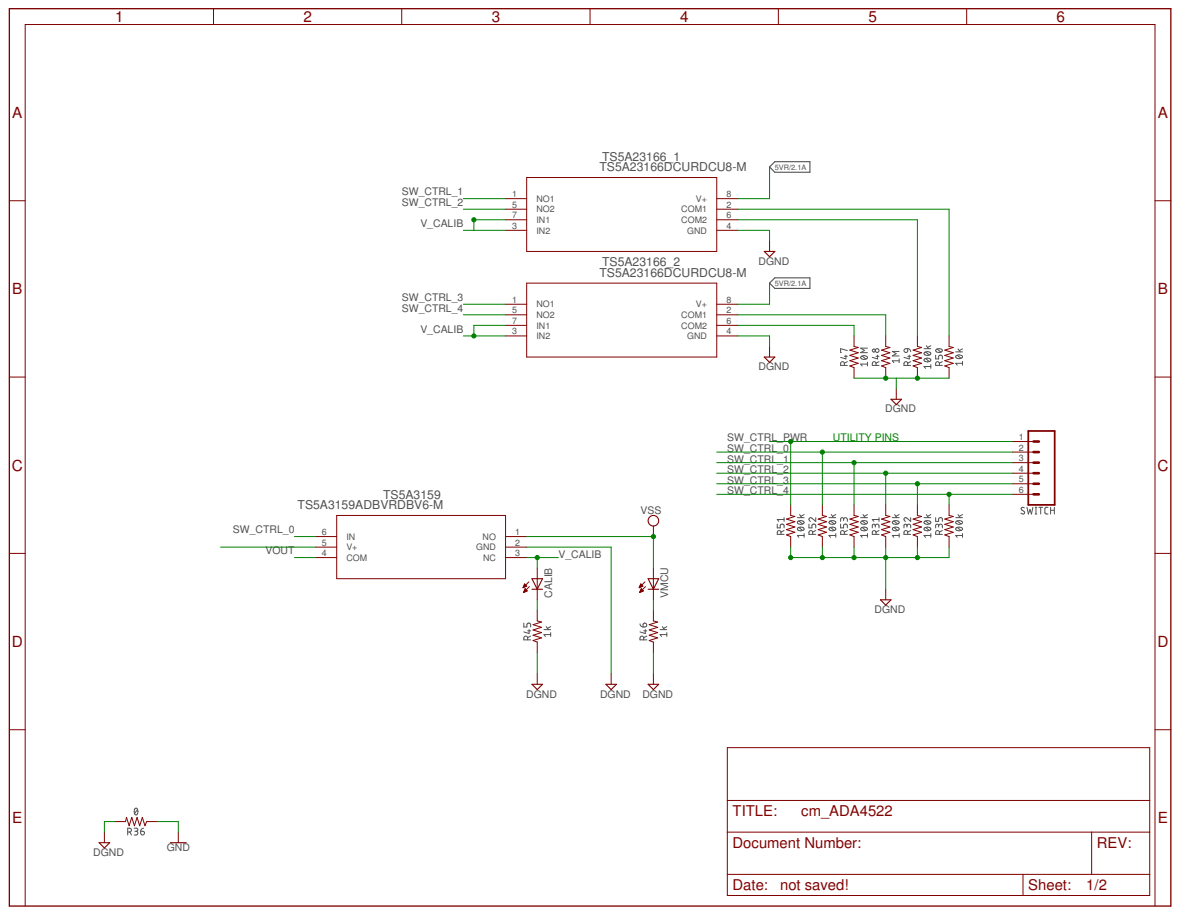
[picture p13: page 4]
TS5A3159ADBVRDBV6-M; DGND; DGND DGND; TS5A23166DCURDCU8-M; VSS; GND; 1 GND 2 NC 3 COM; CALIB; VMCU; COM1; COM2; VOUT; SW_CTRL_1; V_CALIB; SW_CTRL_2; SW_CTRL_3; SW_CTRL_4; SW_CTRL_4 SW_CTRL_0; SW_CTRL_0 SW_CTRL_PWR; UTILITY PINS

REV: TITLE: Document Number: cm_ADA4522

Date: not saved! | Sheet: 1/2

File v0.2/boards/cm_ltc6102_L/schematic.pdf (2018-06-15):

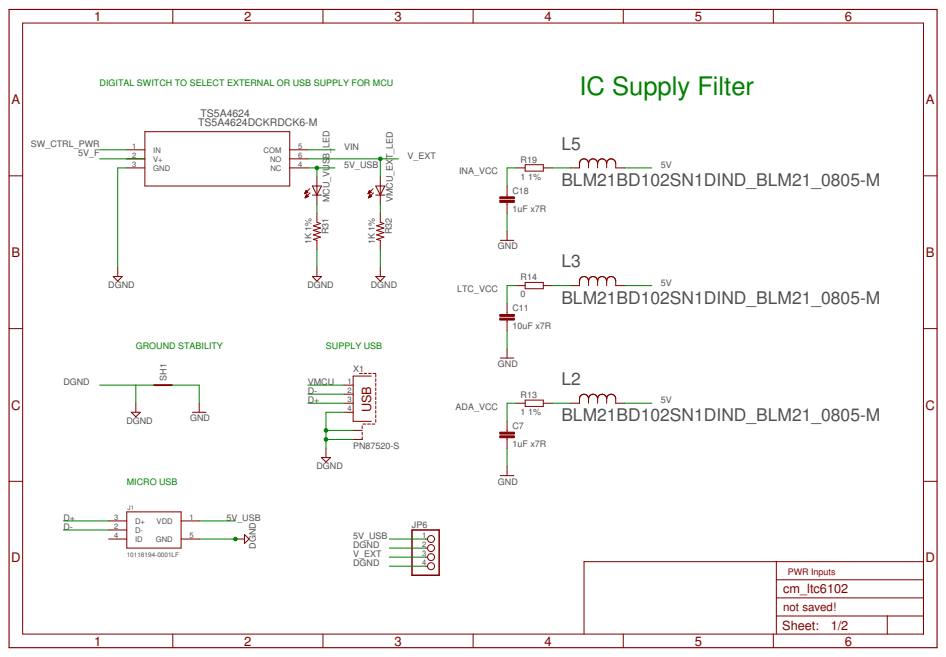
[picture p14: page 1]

DIGITAL SWITCH TO SELECT EXTERNAL OR USB SUPPLY FOR MCU

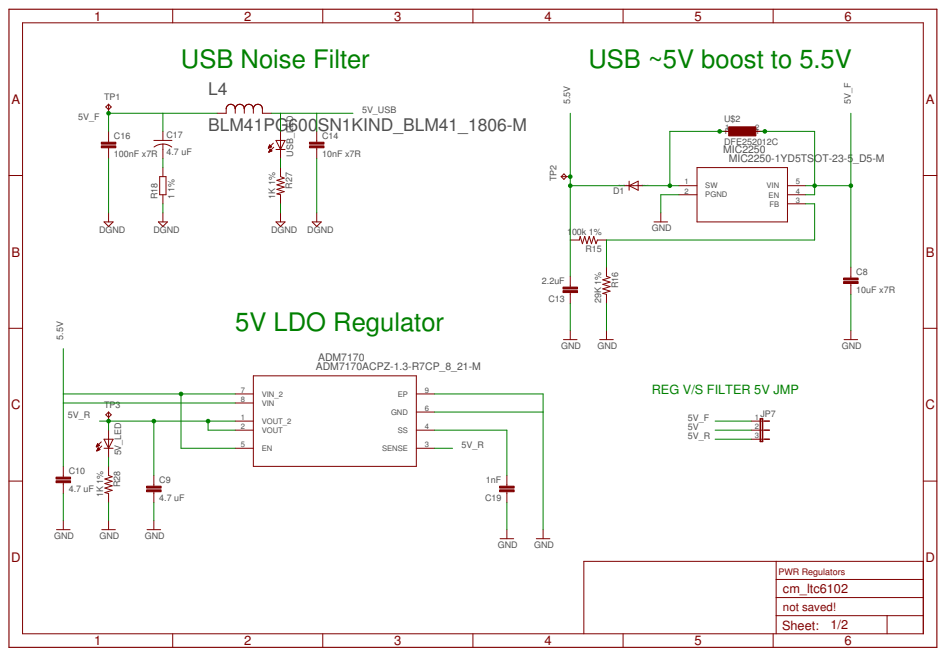
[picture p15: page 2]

P$1 MIC2250-1YD5TSOT-23-5_D5-M

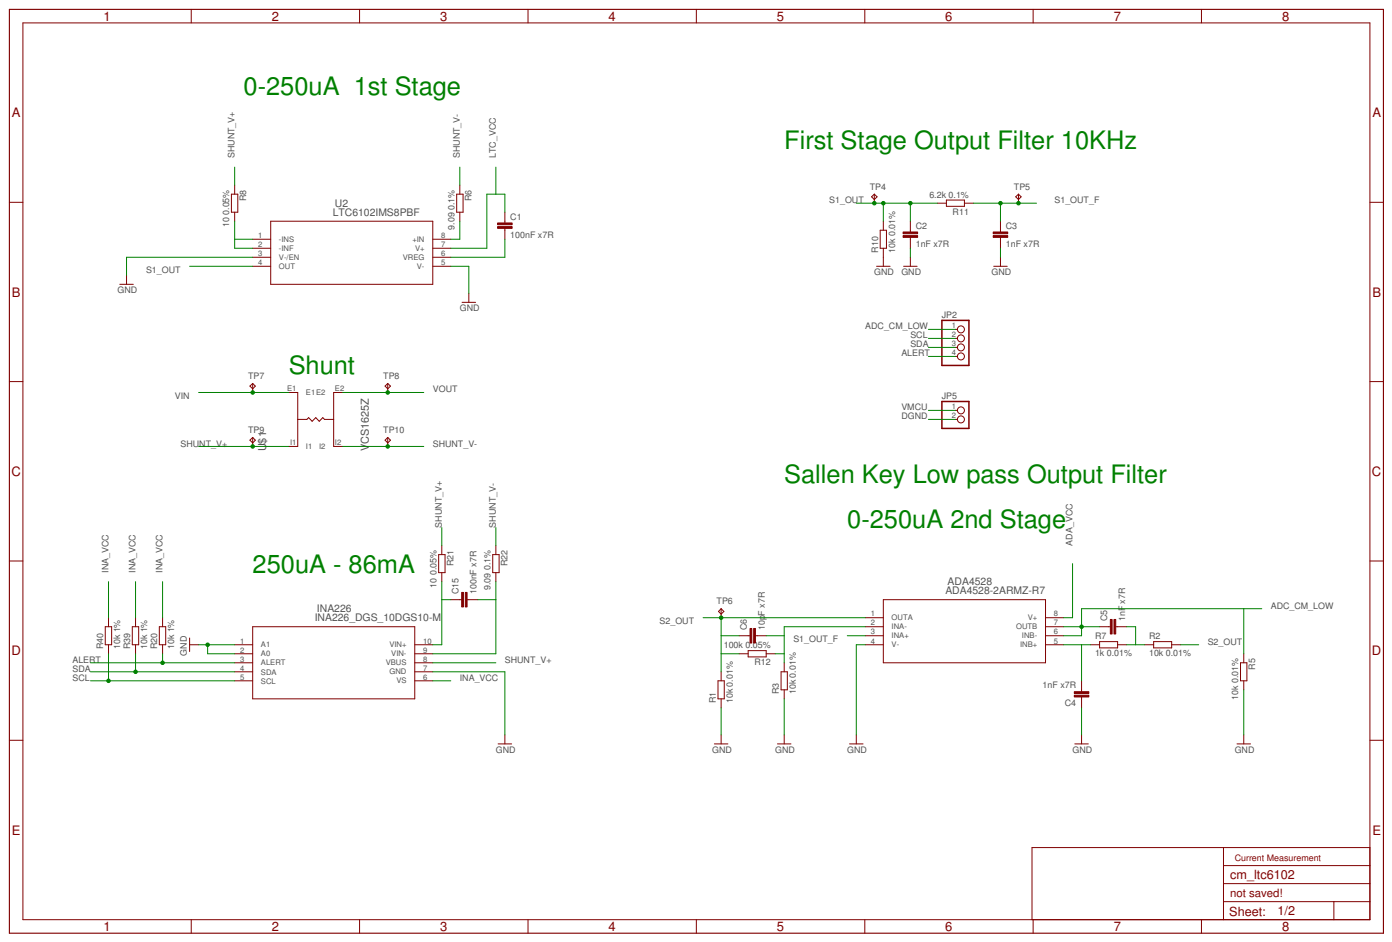
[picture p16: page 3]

First Stage Output Filter 10KHz

Sallen Key Low pass Output Filter
0-250uA 2nd Stage


CALIBRATION RESISTOR DIGITAL SWITCH

EXTERN DIGITAL SWITCH TO SELECT CALIBRATION OR NORMAL OPERATION

ALL SWITCH ARE PD FOR DEFAULT NORMAL OPERATION

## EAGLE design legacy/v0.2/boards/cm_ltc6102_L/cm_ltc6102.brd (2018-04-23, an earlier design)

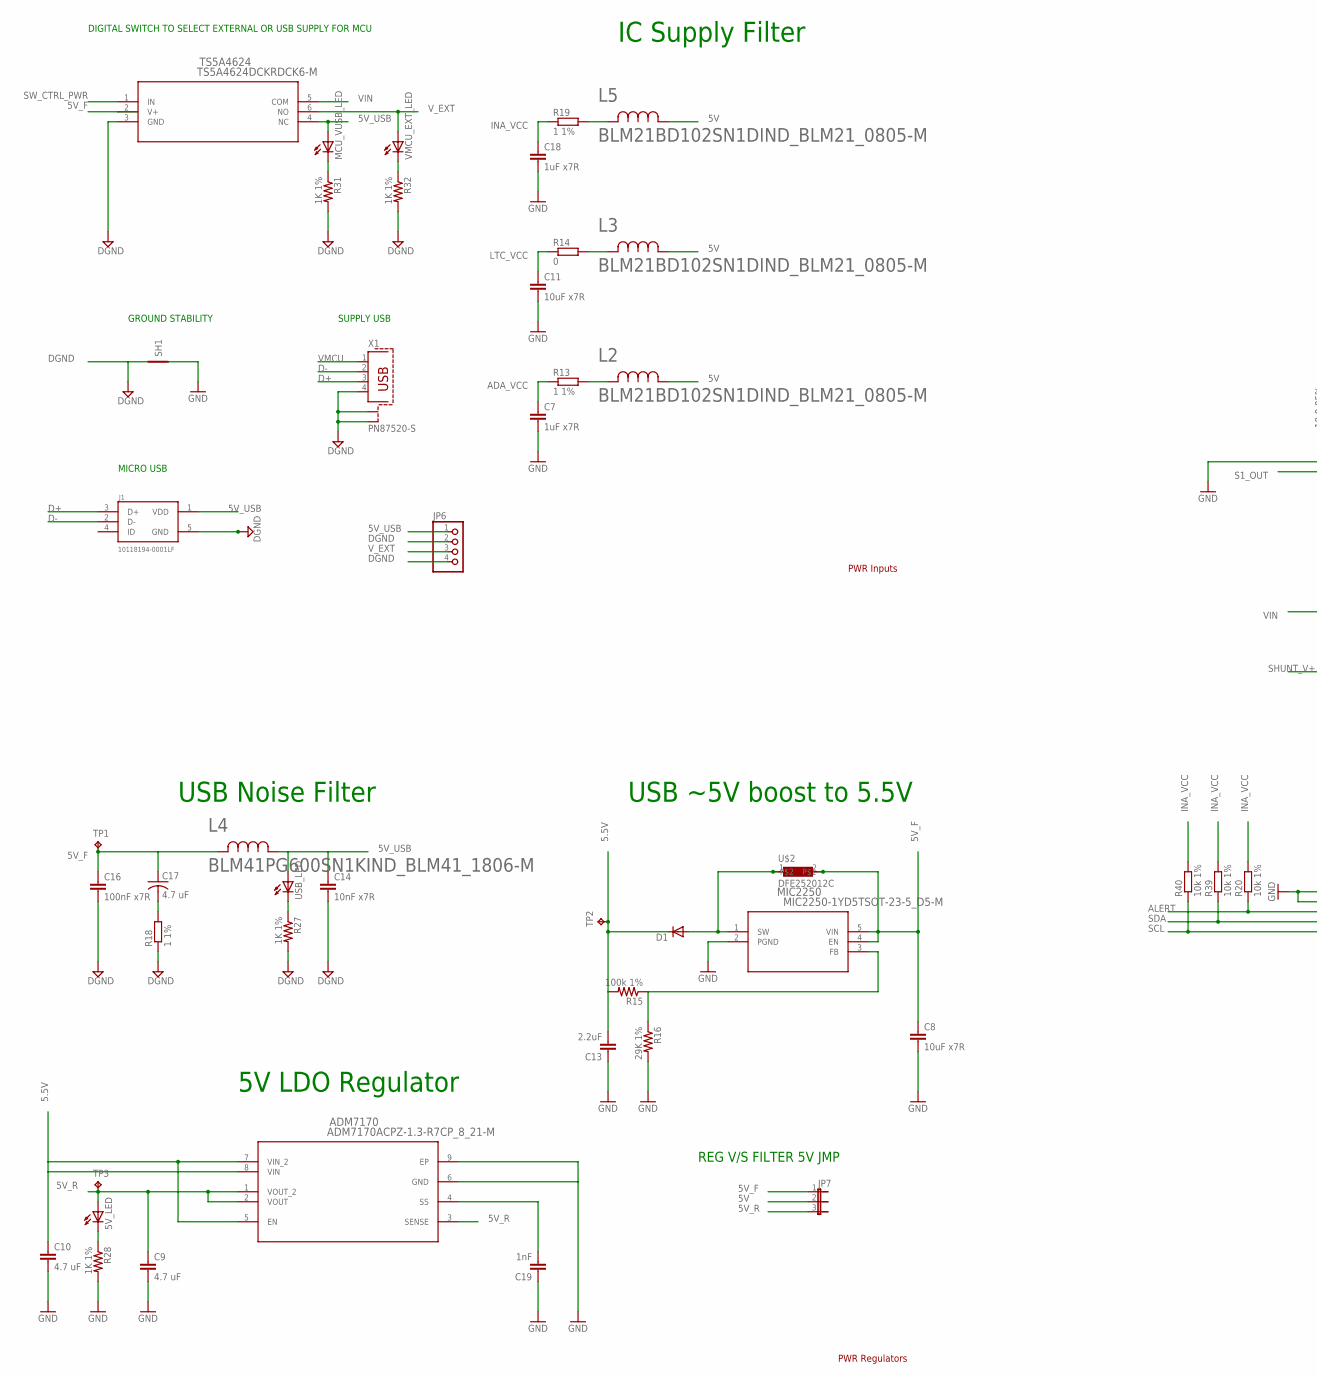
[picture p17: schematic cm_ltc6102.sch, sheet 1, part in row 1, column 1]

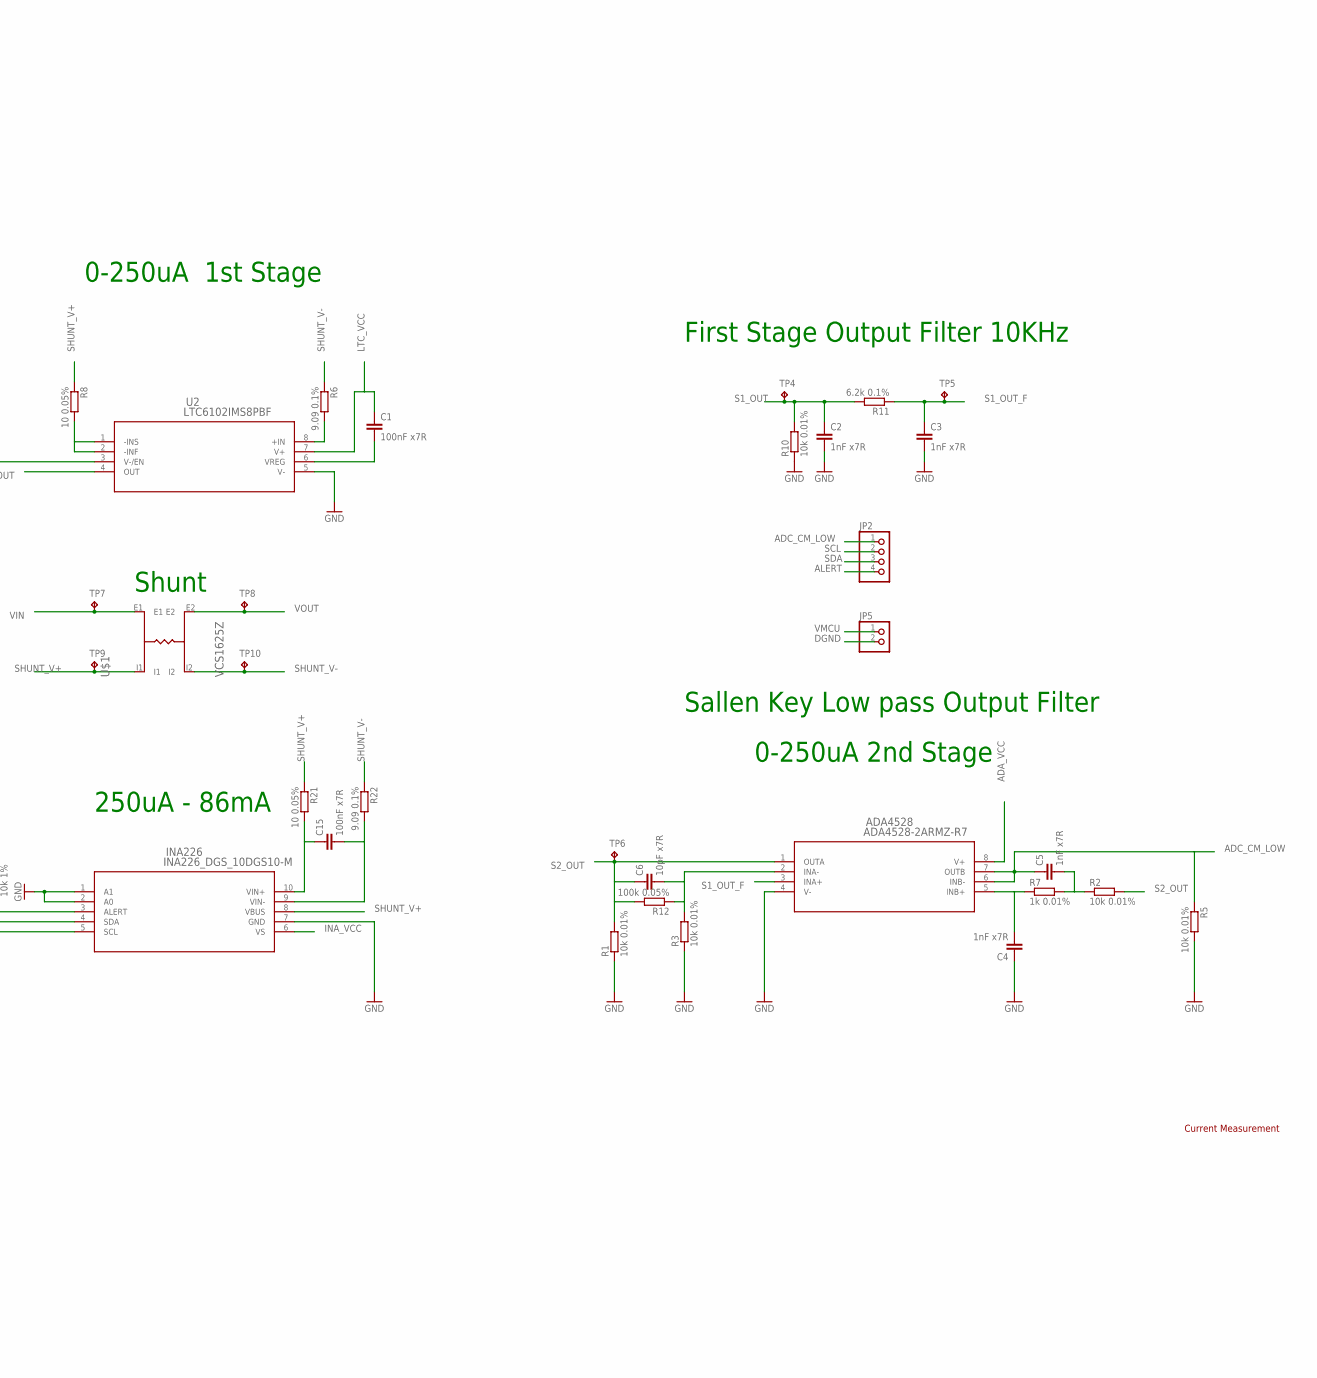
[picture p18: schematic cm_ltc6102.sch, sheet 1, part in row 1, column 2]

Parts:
5V_LED: LEDCHIPLED_0603; CHIPLED_0603
ADA4528: ADA4528-2ARMZ-R7; RM_8
ADM7170: ADM7170ACPZ-1.3-R7CP_8_21-M; CP_8_21-M
C1, C15, C16: 100nF x7R; C0603
C2, C3, C4, C5: 1nF x7R; C0603
C6: 10pF x7R; C0603
C7, C18: 1uF x7R; C0603
C8, C11: 10uF x7R; C0805
C9, C10, C17: 4.7 uF; C1206
C13: 2.2uF; C0603
C14: 10nF x7R; C0603
C19: 1nF; C0603
D1: DIODE-SOD80C; SOD80C
INA226: INA226_DGS_10DGS10-M; DGS10-M
J1: 10118194-0001LF; FRAMATOME_10118194-0001LF
JP2, JP6: PINHD-1X4; 1X04
JP5: PINHD-1X2; 1X02
JP7: JP2E; JP2
L2, L3, L5: BLM21BD102SN1DIND_BLM21_0805-M; IND_BLM21_0805-M
L4: BLM41PG600SN1KIND_BLM41_1806-M; IND_BLM41_1806-M
MCU_VUSB_LED: LEDCHIPLED_0603; CHIPLED_0603
MIC2250: MIC2250-1YD5TSOT-23-5_D5-M; TSOT-23-5_D5-M
R1, R2, R3, R5, R10: 10k 0.01%; R0603
R6, R22: 9.09 0.1%; R0603
R7: 1k 0.01%; R0805
R8, R21: 10 0.05%; R0603
R11: 6.2k 0.1%; R0603
R12: 100k 0.05%; R0603
R13, R18, R19: 1 1%; R0603
R14: 0; R0603
R15: 100k 1%; R0603
R16: 29K 1%; R0603
R20, R39, R40: 10k 1%; R0603
R27, R28, R31, R32: 1K 1%; R0603
SH1: SHORT-VT5; SHORT_TOP-50
TP1, TP2, TP3, TP4, TP5, TP6, TP7, TP8, TP9, TP10: TPPAD1-20; P1-20
TS5A4624: TS5A4624DCKRDCK6-M; DCK6-M
U2: LTC6102IMS8PBF; MSOP-8_MS
U$1: VCS1625Z
U$2: DFE252012C
USB_LED: LEDCHIPLED_0603; CHIPLED_0603
VMCU_EXT_LED: LEDCHIPLED_0603; CHIPLED_0603
X1: PN87520-S

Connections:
5.5V: ADM7170.5 (EN), ADM7170.7 (VIN_2), ADM7170.8 (VIN), C10.1, C13.2, D1.C, R15.2, TP2.TP
5V: JP7.2, L2.1, L3.1, L5.1
5V_F: C8.1, C16.1, C17.1, JP7.1, L4.2, MIC2250.4 (EN), MIC2250.5 (VIN), TP1.TP, TS5A4624.2 (V+), U$2.2; also elsewhere on the board
5V_R: 5V_LED.A, ADM7170.1 (VOUT_2), ADM7170.2 (VOUT), ADM7170.3 (SENSE), C9.1, JP7.3, TP3.TP
5V_USB: C14.1, J1.1 (VDD), JP6.1, L4.1, MCU_VUSB_LED.A, TS5A4624.4 (NC), USB_LED.A
ADA_VCC: ADA4528.8 (V+), C7.1, R13.1
ADC_CM_LOW: ADA4528.6 (INB-), ADA4528.7 (OUTB), C5.1, JP2.1, R5.1
ALERT: INA226.3 (ALERT), JP2.4, R20.1
D+: J1.3 (D+), X1.3
D-: J1.2 (D-), X1.2
DGND: C14.2, C16.2, J1.5 (GND), JP5.2, JP6.2, JP6.4, R18.1, R27.2, R31.2, R32.2, SH1.2, TS5A4624.3 (GND), X1.4, X1.S1, X1.S2; also elsewhere on the board
GND: ADA4528.4 (V-), ADM7170.6 (GND), ADM7170.9 (EP), C2.2, C3.2, C4.1, C7.2, C8.2, C9.2, C10.2, C11.2, C13.1, C18.2, C19.1, INA226.1 (A1), INA226.2 (A0), INA226.7 (GND), MIC2250.2 (PGND), R1.1, R3.1, R5.2, R10.1, R16.2, R28.2, SH1.1, U2.3 (V-/EN), U2.5 (V-)
INA_VCC: C18.1, INA226.6 (VS), R19.1, R20.2, R39.2, R40.2
LTC_VCC: C1.1, C11.1, R14.1, U2.7 (V+)
unnamed: R8.2, U2.1 (-INS), U2.2 (-INF)
unnamed: R6.2, U2.8 (+IN)
unnamed: R27.1, USB_LED.C
unnamed: C1.2, U2.6 (VREG)
unnamed: ADA4528.5 (INB+), C4.2, R7.1
unnamed: C5.2, R2.1, R7.2
unnamed: L3.2, R14.2
unnamed: D1.A, MIC2250.1 (SW), U$2.1
unnamed: ADA4528.2 (INA-), C6.2, R3.2, R12.1
unnamed: L2.2, R13.2
unnamed: C15.1, INA226.10 (VIN+), R21.2
unnamed: ADM7170.4 (SS), C19.2
unnamed: MIC2250.3 (FB), R15.1, R16.1
unnamed: C17.2, R18.2
unnamed: L5.2, R19.2
unnamed: C15.2, INA226.9 (VIN-), R22.2
unnamed: 5V_LED.C, R28.1
unnamed: MCU_VUSB_LED.C, R31.1
unnamed: R32.1, VMCU_EXT_LED.C
S1_OUT: C2.1, R10.2, R11.2, TP4.TP, U2.4 (OUT)
S1_OUT_F: ADA4528.3 (INA+), C3.1, R11.1, TP5.TP
S2_OUT: ADA4528.1 (OUTA), C6.1, R1.2, R2.2, R12.2, TP6.TP
SCL: INA226.5 (SCL), JP2.2, R40.1
SDA: INA226.4 (SDA), JP2.3, R39.1
SHUNT_V+: INA226.8 (VBUS), R8.1, R21.1, TP9.TP, U$1.I1
SHUNT_V-: R6.1, R22.1, TP10.TP, U$1.I2
SW_CTRL_PWR: TS5A4624.1 (IN); also elsewhere on the board
VIN: TP7.TP, TS5A4624.5 (COM), U$1.E1
VMCU: JP5.1, X1.1; also elsewhere on the board
VOUT: TP8.TP, U$1.E2; also elsewhere on the board
V_EXT: JP6.3, TS5A4624.6 (NO), VMCU_EXT_LED.A

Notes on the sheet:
USB Noise Filter
USB ~5V boost to 5.5V
5V LDO Regulator
IC Supply Filter
First Stage Output Filter 10KHz
Sallen Key Low pass Output Filter
0-250uA 2nd Stage
0-250uA 1st Stage
250uA - 86mA
Shunt
SUPPLY USB
MICRO USB
GROUND STABILITY
REG V/S FILTER 5V JMP
DIGITAL SWITCH TO SELECT EXTERNAL OR USB SUPPLY FOR MCU
Current Measurement
PWR Regulators
PWR Inputs

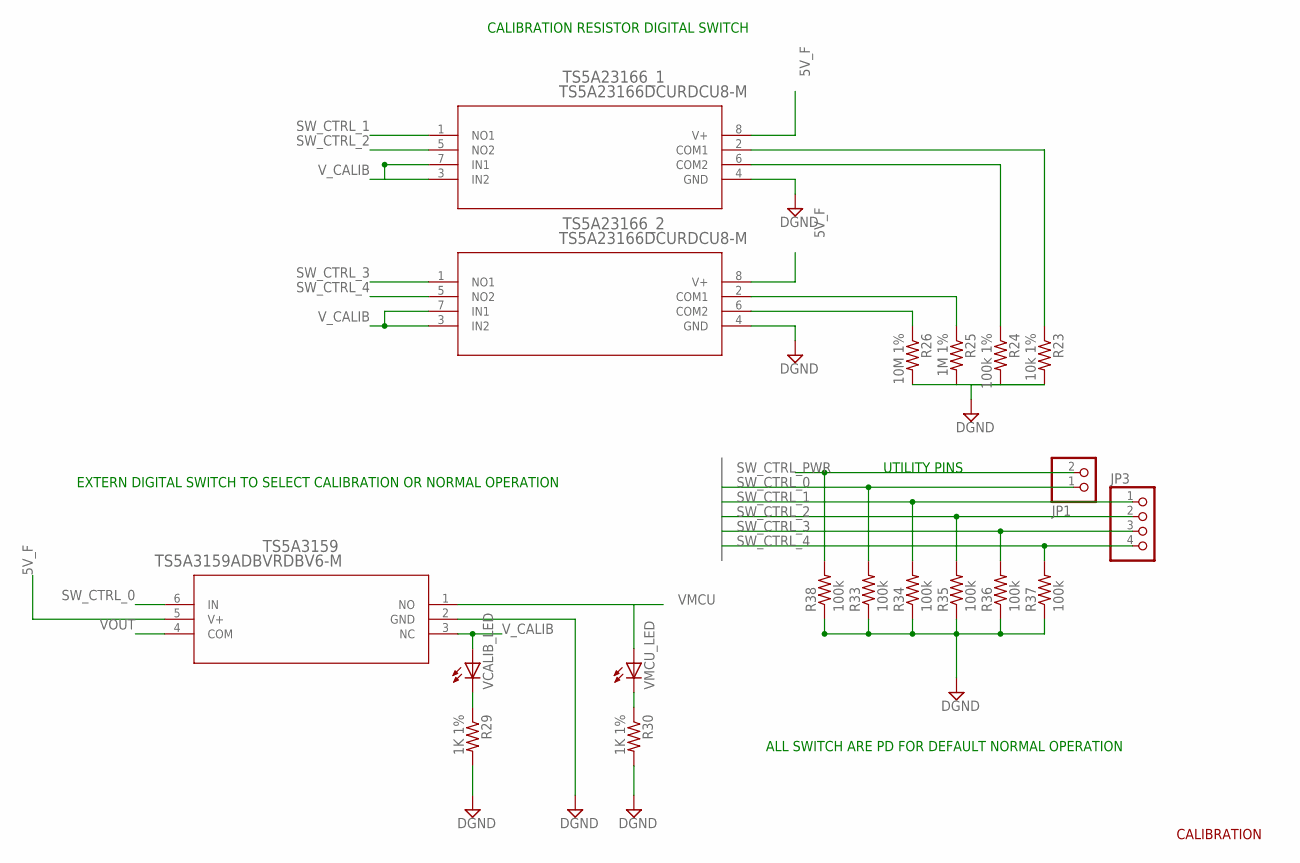
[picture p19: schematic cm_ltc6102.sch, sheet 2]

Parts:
JP1: PINHD-1X2; 1X02
JP3: PINHD-1X4; 1X04
R23: 10k 1%; R0603
R24: 100k 1%; R0603
R25: 1M 1%; R0603
R26: 10M 1%; R0603
R29, R30: 1K 1%; R0603
R33, R34, R35, R36, R37, R38: 100k; R0805
TS5A3159: TS5A3159ADBVRDBV6-M; DBV6-M
TS5A23166_1, TS5A23166_2: TS5A23166DCURDCU8-M; DCU8-M
VCALIB_LED: LEDCHIPLED_0603; CHIPLED_0603
VMCU_LED: LEDCHIPLED_0603; CHIPLED_0603

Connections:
5V_F: TS5A3159.5 (V+), TS5A23166_1.8 (V+), TS5A23166_2.8 (V+); also elsewhere on the board
DGND: R23.2, R24.2, R25.2, R26.2, R29.2, R30.2, R33.1, R34.1, R35.1, R36.1, R37.1, R38.1, TS5A3159.2 (GND), TS5A23166_1.4 (GND), TS5A23166_2.4 (GND); also elsewhere on the board
unnamed: R29.1, VCALIB_LED.C
unnamed: R30.1, VMCU_LED.C
unnamed: R23.1, TS5A23166_1.2 (COM1)
unnamed: R24.1, TS5A23166_1.6 (COM2)
unnamed: R25.1, TS5A23166_2.2 (COM1)
unnamed: R26.1, TS5A23166_2.6 (COM2)
SW_CTRL_0: JP1.1, R33.2, TS5A3159.6 (IN)
SW_CTRL_1: JP3.1, R34.2, TS5A23166_1.1 (NO1)
SW_CTRL_2: JP3.2, R35.2, TS5A23166_1.5 (NO2)
SW_CTRL_3: JP3.3, R36.2, TS5A23166_2.1 (NO1)
SW_CTRL_4: JP3.4, R37.2, TS5A23166_2.5 (NO2)
SW_CTRL_PWR: JP1.2, R38.2; also elsewhere on the board
VMCU: TS5A3159.1 (NO), VMCU_LED.A; also elsewhere on the board
VOUT: TS5A3159.4 (COM); also elsewhere on the board
V_CALIB: TS5A3159.3 (NC), TS5A23166_1.3 (IN2), TS5A23166_1.7 (IN1), TS5A23166_2.3 (IN2), TS5A23166_2.7 (IN1), VCALIB_LED.A

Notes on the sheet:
UTILITY PINS
EXTERN DIGITAL SWITCH TO SELECT CALIBRATION OR NORMAL OPERATION
ALL SWITCH ARE PD FOR DEFAULT NORMAL OPERATION
CALIBRATION RESISTOR DIGITAL SWITCH
CALIBRATION

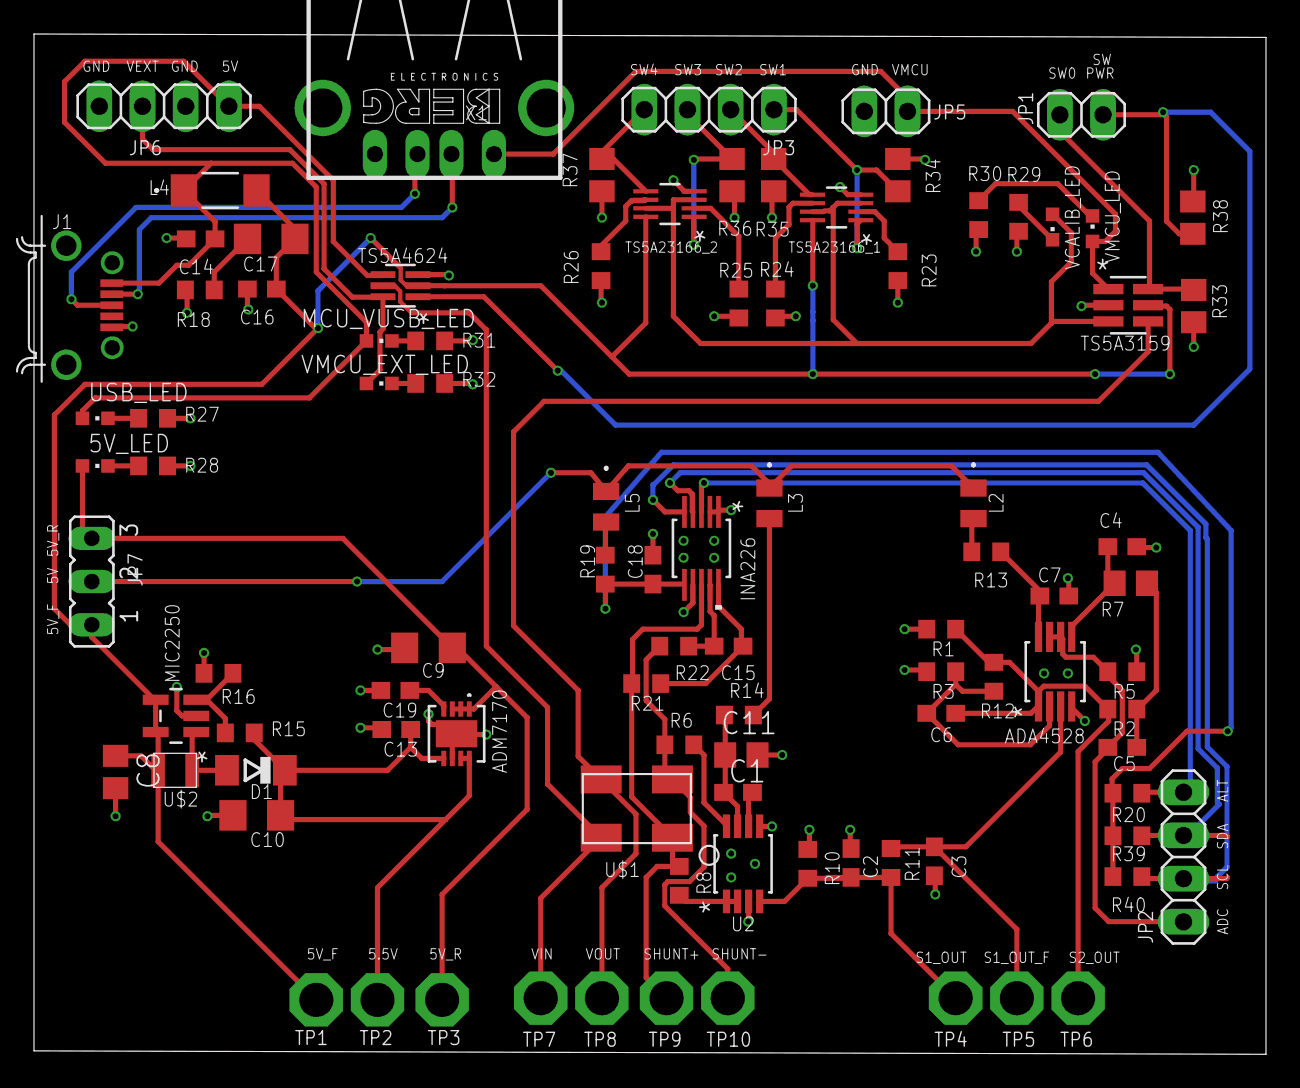
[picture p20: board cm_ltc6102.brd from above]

Board: 2 copper layers, 72.5 x 60.0 mm, 96 parts (1 on the bottom side), 57 nets.

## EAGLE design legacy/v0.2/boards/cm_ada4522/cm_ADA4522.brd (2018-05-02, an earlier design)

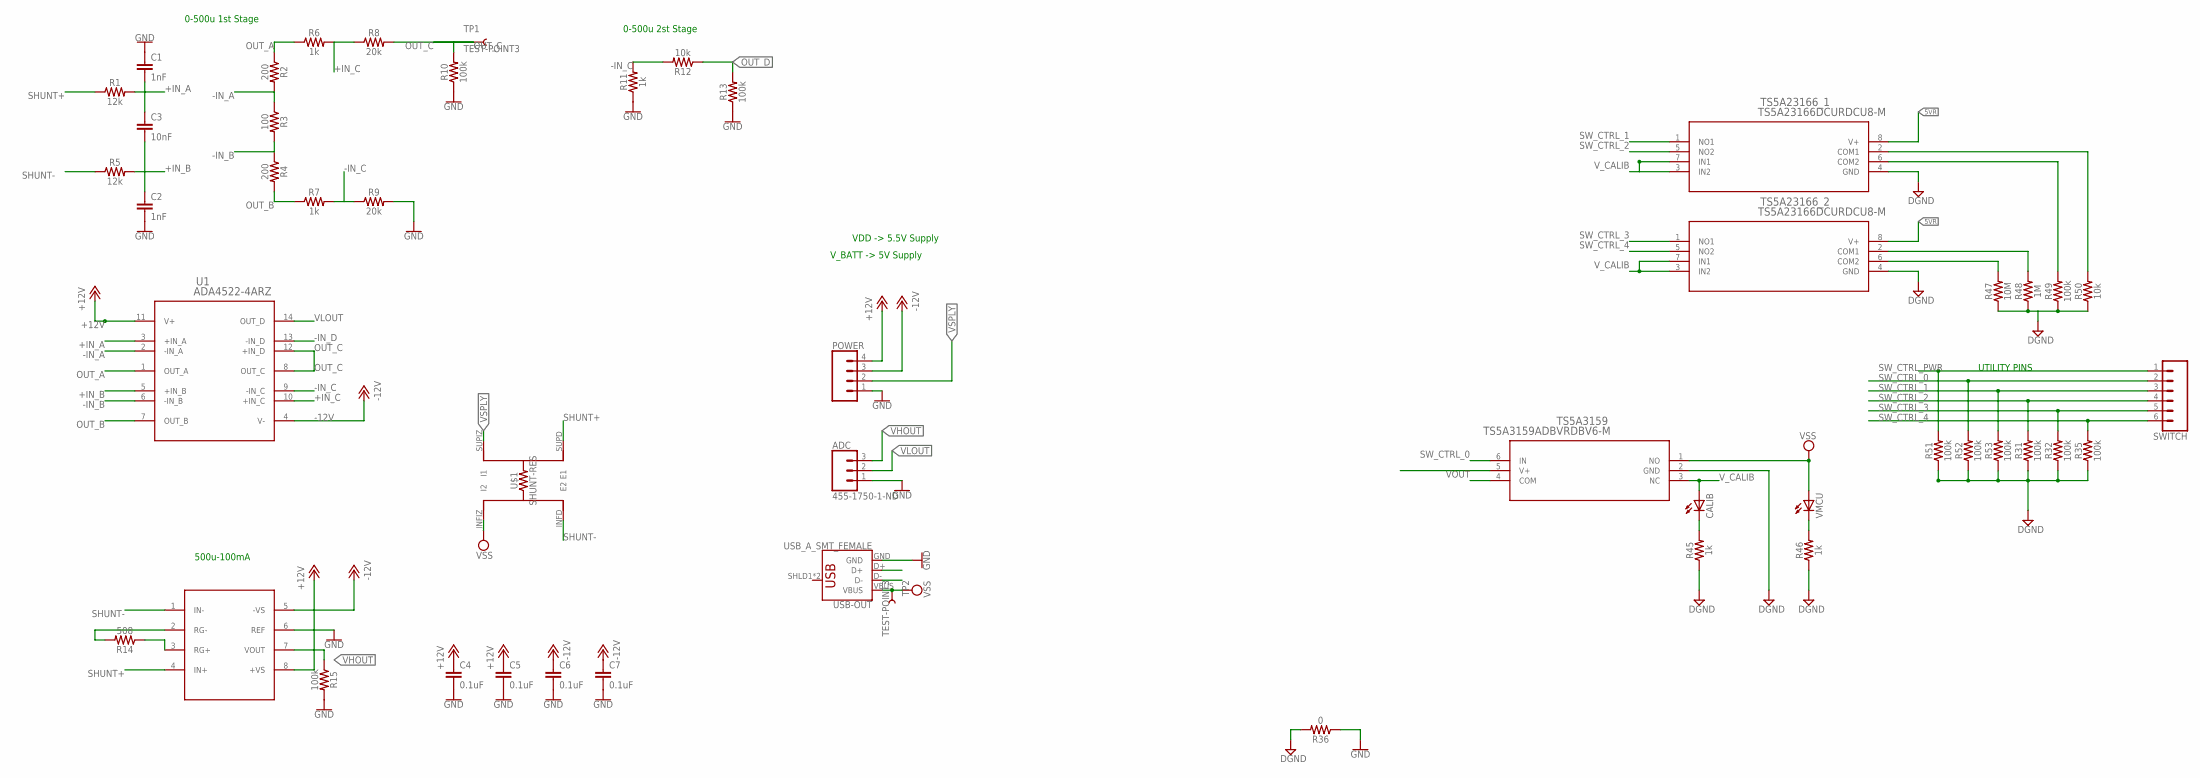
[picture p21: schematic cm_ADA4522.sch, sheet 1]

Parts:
AD8422: AD8422; SO08
ADC: 455-1750-1-ND; 1X03
C1, C2: 1nF; 0603
C3: 10nF; 0603
C4, C5, C6, C7: 0.1uF; 0603
CALIB: LEDCHIPLED_0603; CHIPLED_0603
POWER: CONN_04; 1X04
R1, R5: 12k; 0603
R2, R4: 200; 0603
R3: 100; 0603
R6, R7, R11, R45, R46: 1k; 0603
R8, R9: 20k; 0603
R10, R13, R15, R31, R32, R35, R49, R51, R52, R53: 100k; 0603
R12, R50: 10k; 0603
R14: 508; 0603
R36: 0; 0603
R47: 10M; 0603
R48: 1M; 0603
SWITCH: CONN_06LONGPADS; 1X06_LONGPADS
TP1, TP2: TEST-POINT3; PAD.03X.03
TS5A3159: TS5A3159ADBVRDBV6-M; DBV6-M
TS5A23166_1, TS5A23166_2: TS5A23166DCURDCU8-M; DCU8-M
U1: ADA4522-4ARZ; R_14
U$1: SHUNT-RES; HIPREC-SMD-SHUNT
USB-OUT: USB_A_SMT_FEMALE; USB-A-S-SILK-FEMALE
VMCU: LEDCHIPLED_0603; CHIPLED_0603

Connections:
5VR: TS5A23166_1.8 (V+), TS5A23166_2.8 (V+); also elsewhere on the board
5V_F: TS5A3159.5 (V+)
+12V: AD8422.8 (+VS), C4.1, C5.1, POWER.4, U1.11 (V+); also elsewhere on the board
+IN_A: C1.2, C3.1, R1.2, U1.3 (+IN_A)
+IN_B: C2.1, C3.2, R5.2, U1.5 (+IN_B)
+IN_C: R6.2, R8.1, U1.10 (+IN_C)
-12V: AD8422.5 (-VS), C6.1, C7.1, POWER.3, U1.4 (V-); also elsewhere on the board
-IN_A: R2.2, R3.1, U1.2 (-IN_A)
-IN_B: R3.2, R4.1, U1.6 (-IN_B)
-IN_C: R7.2, R9.1, R11.2, R12.2, U1.9 (-IN_C)
-IN_D: U1.13 (-IN_D)
DATA+: USB-OUT.D+; also elsewhere on the board
DATA-: USB-OUT.D-; also elsewhere on the board
DGND: R31.1, R32.1, R35.1, R36.2, R45.1, R46.1, R47.1, R48.1, R49.1, R50.1, R51.1, R52.1, R53.1, TS5A3159.2 (GND), TS5A23166_1.4 (GND), TS5A23166_2.4 (GND); also elsewhere on the board
GND: AD8422.6 (REF), ADC.1, C1.1, C2.2, C4.2, C5.2, C6.2, C7.2, POWER.1, R9.2, R10.1, R11.1, R13.1, R15.2, R36.1, USB-OUT.GND; also elsewhere on the board
unnamed: AD8422.2 (RG-), R14.2
unnamed: AD8422.3 (RG+), R14.1
unnamed: CALIB.C, R45.2
unnamed: R46.2, VMCU.C
unnamed: R50.2, TS5A23166_1.2 (COM1)
unnamed: R49.2, TS5A23166_1.6 (COM2)
unnamed: R48.2, TS5A23166_2.2 (COM1)
unnamed: R47.2, TS5A23166_2.6 (COM2)
OUT_A: R2.1, R6.1, U1.1 (OUT_A)
OUT_B: R4.2, R7.1, U1.7 (OUT_B)
OUT_C: R8.2, R10.2, TP1.P$1, U1.8 (OUT_C), U1.12 (+IN_D)
OUT_D: R12.1, R13.2
SHUNT+: AD8422.4 (IN+), R1.1, U$1.SUPD (E1)
SHUNT-: AD8422.1 (IN-), R5.1, U$1.INFD (E2)
SW_CTRL_0: R52.2, SWITCH.2, TS5A3159.6 (IN)
SW_CTRL_1: R53.2, SWITCH.3, TS5A23166_1.1 (NO1)
SW_CTRL_2: R31.2, SWITCH.4, TS5A23166_1.5 (NO2)
SW_CTRL_3: R32.2, SWITCH.5, TS5A23166_2.1 (NO1)
SW_CTRL_4: R35.2, SWITCH.6, TS5A23166_2.5 (NO2)
SW_CTRL_PWR: R51.2, SWITCH.1; also elsewhere on the board
VHOUT: AD8422.7 (VOUT), ADC.3, R15.1
VLOUT: ADC.2, U1.14 (OUT_D)
VOUT: TS5A3159.4 (COM)
VSPLY: POWER.2, U$1.SUPIZ (I1); also elsewhere on the board
VSS: TP2.P$1, TS5A3159.1 (NO), U$1.INFIZ (I2), USB-OUT.VBUS, VMCU.A
V_CALIB: CALIB.A, TS5A3159.3 (NC), TS5A23166_1.3 (IN2), TS5A23166_1.7 (IN1), TS5A23166_2.3 (IN2), TS5A23166_2.7 (IN1)

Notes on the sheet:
0-500u 1st Stage
500u-100mA
0-500u 2st Stage
VDD -> 5.5V Supply
V_BATT -> 5V Supply
UTILITY PINS

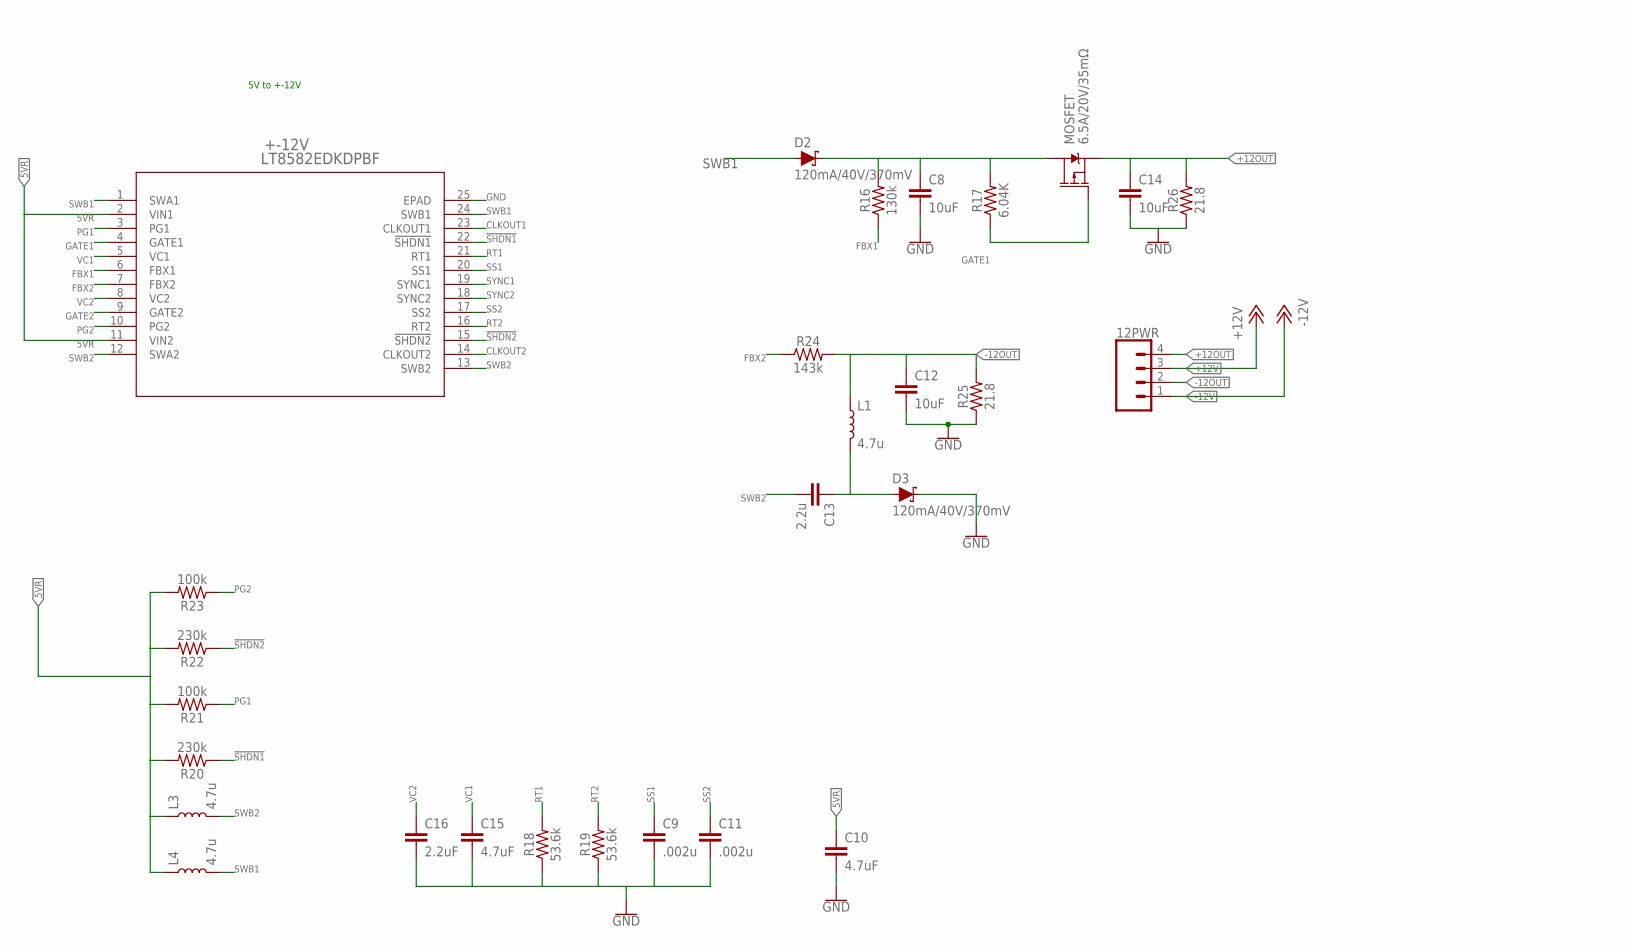
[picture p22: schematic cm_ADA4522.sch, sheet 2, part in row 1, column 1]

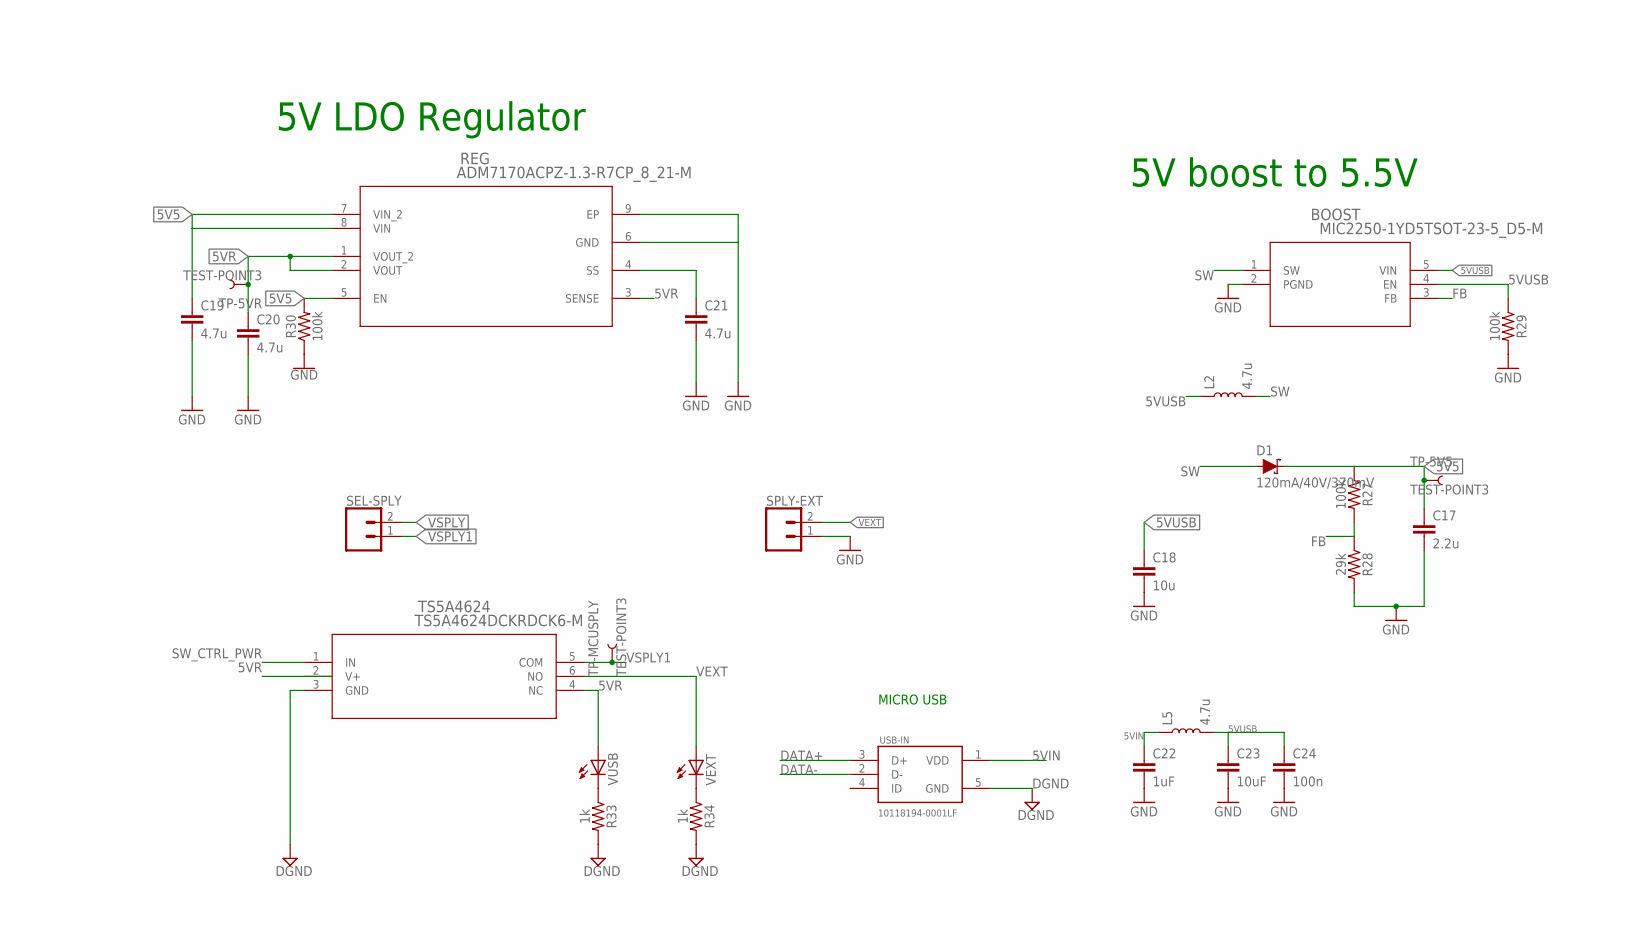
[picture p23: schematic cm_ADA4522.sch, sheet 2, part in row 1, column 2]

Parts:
12PWR: CONN_04; 1X04
+-12V: LT8582EDKDPBF; DFN-24_DKD
BOOST: MIC2250-1YD5TSOT-23-5_D5-M; TSOT-23-5_D5-M
C8, C12, C14, C23: 10uF; 0603
C9, C11: .002u; 0603
C10, C15: 4.7uF; 0603
C13, C17: 2.2u; 0603
C16: 2.2uF; 0603
C18: 10u; 0603
C19, C20, C21: 4.7u; 0603
C22: 1uF; 0603
C24: 100n; 0603
D1, D2, D3: 120mA/40V/370mV; SOD-523
L1, L2, L3, L4, L5: 4.7u; 252012C
MOSFET: 6.5A/20V/35mΩ; SO08
R16: 130k; 0603
R17: 6.04K; 0603
R18, R19: 53.6k; 0603
R20, R22: 230k; 0603
R21, R23, R27, R29, R30: 100k; 0603
R24: 143k; 0603
R25, R26: 21.8; 0603
R28: 29k; 0603
R33, R34: 1k; 0603
REG: ADM7170ACPZ-1.3-R7CP_8_21-M; CP_8_21-M
SEL-SPLY: CONN_02; 1X02
SPLY-EXT: CONN_02; 1X02
TP-5V5, TP-5VR: TEST-POINT3; PAD.03X.03
TP-MCUSPLY: TEST-POINT3; PAD.03X.03
TS5A4624: TS5A4624DCKRDCK6-M; DCK6-M
USB-IN: 10118194-0001LF; FRAMATOME_10118194-0001LF
VEXT: LEDCHIPLED_0603; CHIPLED_0603
VUSB: LEDCHIPLED_0603; CHIPLED_0603

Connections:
5V5: C17.1, C19.1, D1.C, R27.1, R30.2, REG.5 (EN), REG.7 (VIN_2), REG.8 (VIN), TP-5V5.P$1
5VIN: C22.1, L5.1, USB-IN.1 (VDD)
5VR: +-12V.2 (VIN1), +-12V.11 (VIN2), C10.1, C20.1, L3.1, L4.1, R20.2, R21.2, R22.2, R23.2, REG.1 (VOUT_2), REG.2 (VOUT), REG.3 (SENSE), TP-5VR.P$1, TS5A4624.2 (V+), TS5A4624.4 (NC), VUSB.A; also elsewhere on the board
5VUSB: BOOST.4 (EN), BOOST.5 (VIN), C18.1, C23.1, C24.1, L2.1, L5.2, R29.1
!SHDN1: +-12V.22 (!SHDN1), R20.1
!SHDN2: +-12V.15 (!SHDN2), R22.1
+12OUT: 12PWR.4, C14.1, MOSFET.1 (S), MOSFET.2 (S), MOSFET.3 (S), R26.2
+12V: 12PWR.3; also elsewhere on the board
-12OUT: 12PWR.2, C12.1, L1.1, R24.2, R25.2
-12V: 12PWR.1; also elsewhere on the board
CLKOUT1: +-12V.23 (CLKOUT1)
CLKOUT2: +-12V.14 (CLKOUT2)
DATA+: USB-IN.3 (D+); also elsewhere on the board
DATA-: USB-IN.2 (D-); also elsewhere on the board
DGND: R33.2, R34.2, TS5A4624.3 (GND), USB-IN.5 (GND); also elsewhere on the board
FB: BOOST.3 (FB), R27.2, R28.1
FBX1: +-12V.6 (FBX1), R16.1
FBX2: +-12V.7 (FBX2), R24.1
GATE1: +-12V.4 (GATE1), MOSFET.4 (G), R17.1
GATE2: +-12V.9 (GATE2)
GND: +-12V.25 (EPAD), BOOST.2 (PGND), C8.2, C9.2, C10.2, C11.2, C12.2, C14.2, C15.2, C16.2, C17.2, C18.2, C19.2, C20.2, C21.2, C22.2, C23.2, C24.2, D3.C, R18.1, R19.1, R25.1, R26.1, R28.2, R29.2, R30.1, REG.6 (GND), REG.9 (EP), SPLY-EXT.1; also elsewhere on the board
unnamed: R33.1, VUSB.C
unnamed: C8.1, D2.C, MOSFET.5 (D), MOSFET.6 (D), MOSFET.7 (D), MOSFET.8 (D), R16.2, R17.2
unnamed: C13.1, D3.A, L1.2
unnamed: R34.1, VEXT.C
unnamed: C21.1, REG.4 (SS)
PG1: +-12V.3 (PG1), R21.1
PG2: +-12V.10 (PG2), R23.1
RT1: +-12V.21 (RT1), R18.2
RT2: +-12V.16 (RT2), R19.2
SS1: +-12V.20 (SS1), C9.1
SS2: +-12V.17 (SS2), C11.1
SW: BOOST.1 (SW), D1.A, L2.2
SWB1: +-12V.1 (SWA1), +-12V.24 (SWB1), D2.A, L4.2
SWB2: +-12V.12 (SWA2), +-12V.13 (SWB2), C13.2, L3.2
SW_CTRL_PWR: TS5A4624.1 (IN); also elsewhere on the board
SYNC1: +-12V.19 (SYNC1)
SYNC2: +-12V.18 (SYNC2)
VC1: +-12V.5 (VC1), C15.1
VC2: +-12V.8 (VC2), C16.1
VEXT: SPLY-EXT.2, TS5A4624.6 (NO), VEXT.A
VSPLY: SEL-SPLY.2; also elsewhere on the board
VSPLY1: SEL-SPLY.1, TP-MCUSPLY.P$1, TS5A4624.5 (COM)

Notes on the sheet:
5V to +-12V
5V boost to 5.5V
5V LDO Regulator
MICRO USB

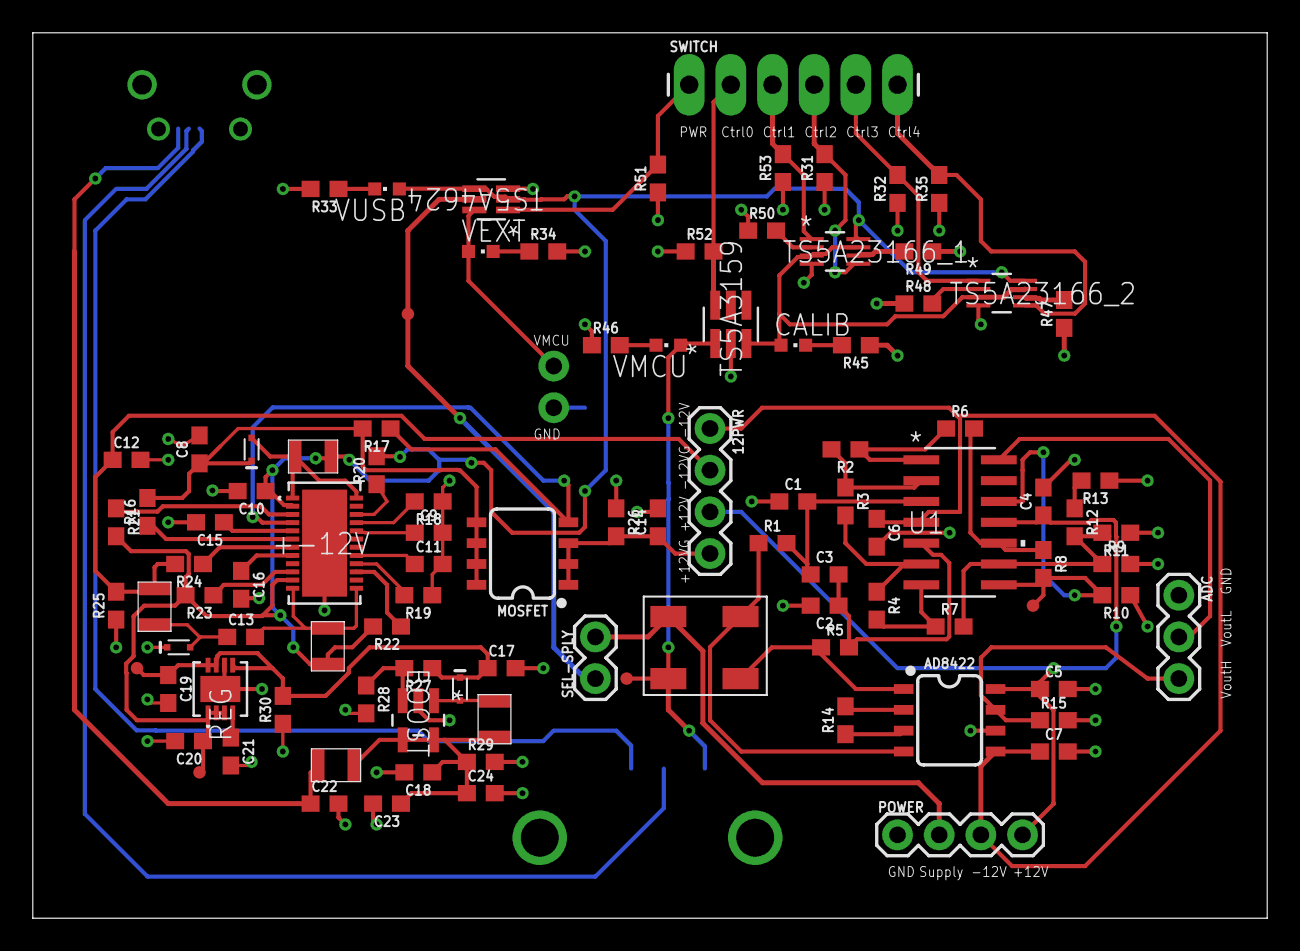
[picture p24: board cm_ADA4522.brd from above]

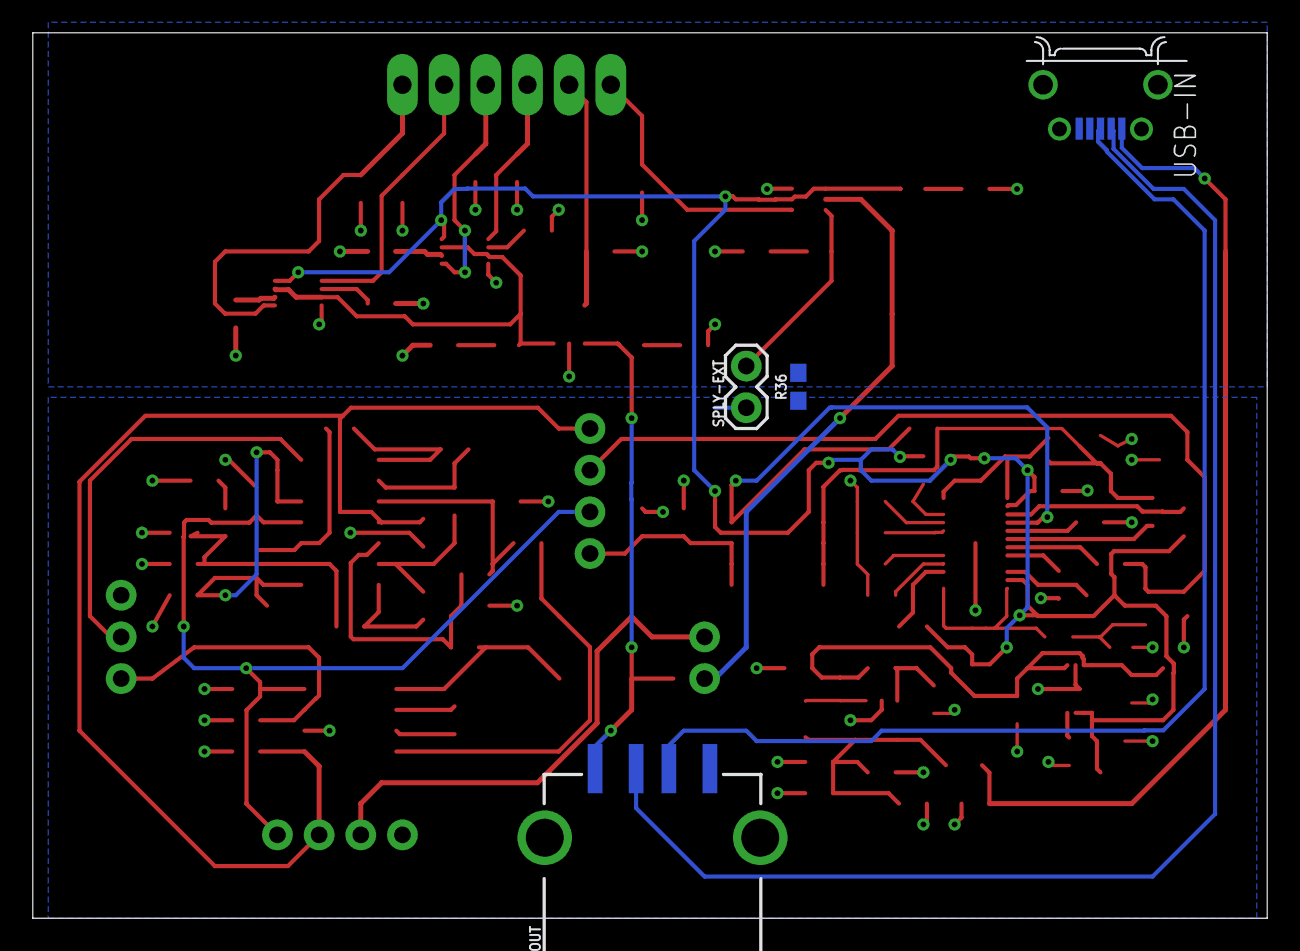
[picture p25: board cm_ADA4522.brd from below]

Board: 2 copper layers, 75.2 x 54.0 mm, 105 parts (4 on the bottom side), 67 nets.

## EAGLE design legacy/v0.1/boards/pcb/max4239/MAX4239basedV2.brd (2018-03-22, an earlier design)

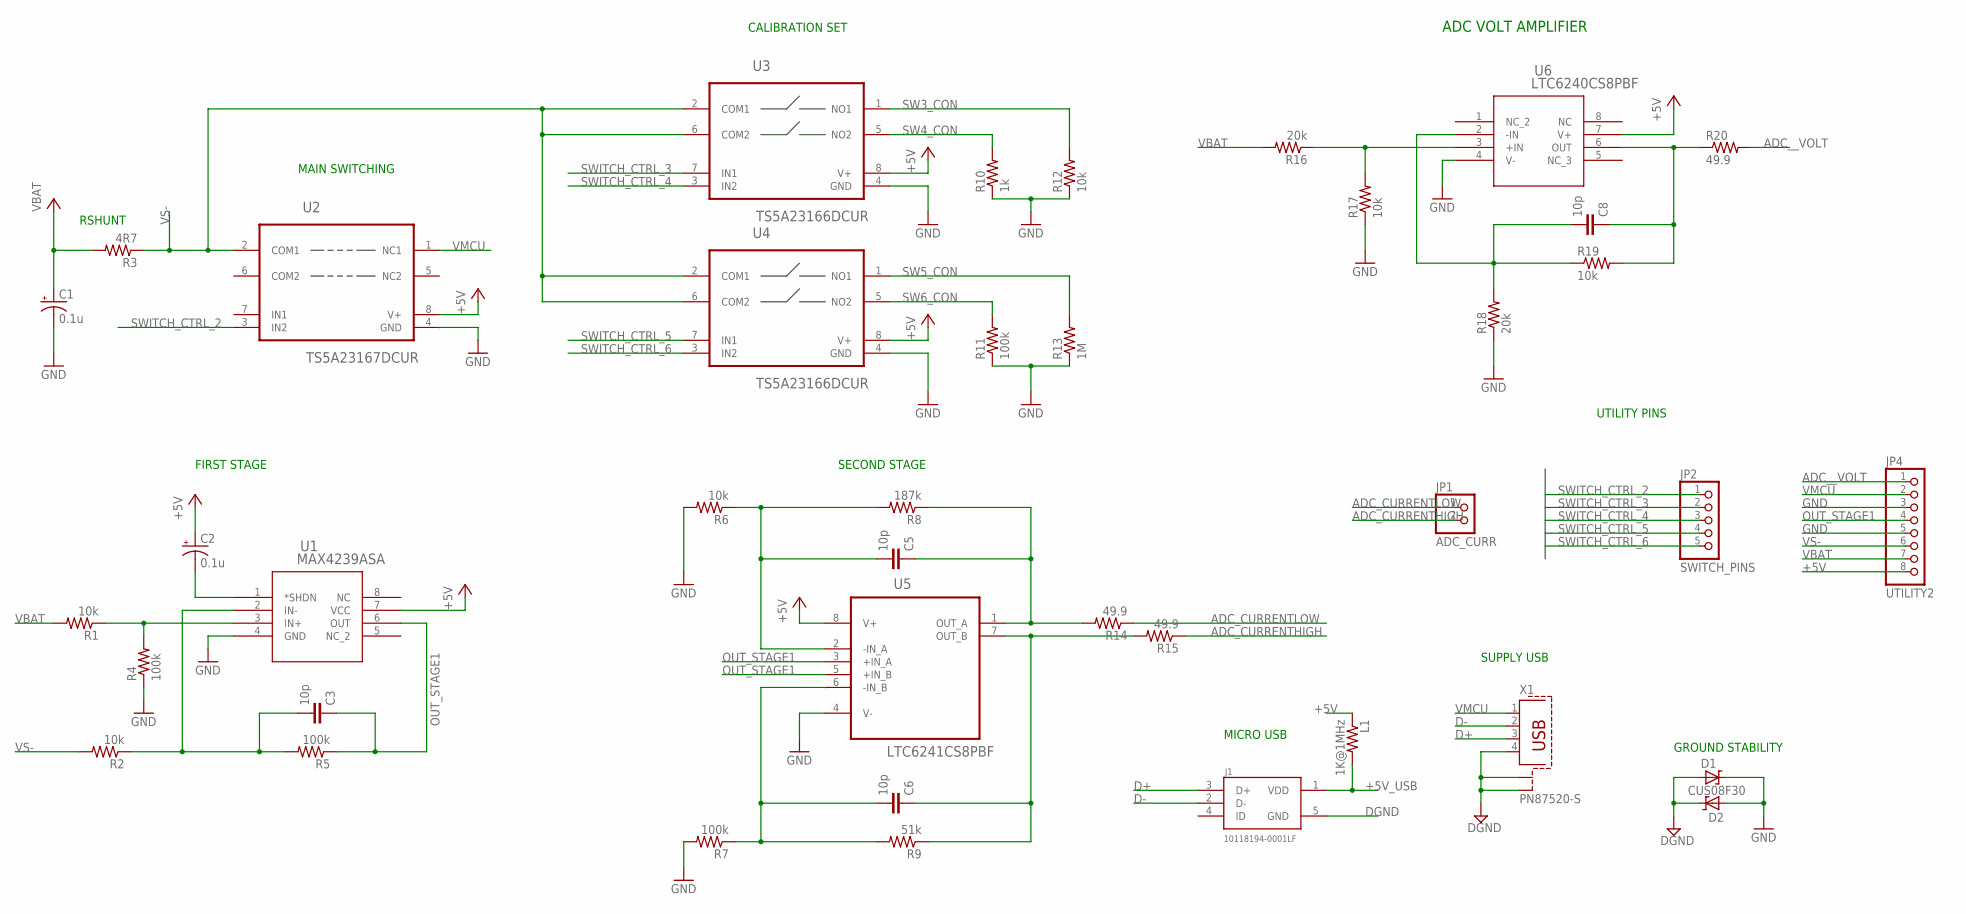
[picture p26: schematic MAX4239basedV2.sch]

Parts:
C1, C2: 0.1u; PANASONIC_B
C3, C5, C6, C8: 10p; C0805
D1, D2: CUS08F30; SOD323
J1: 10118194-0001LF; FRAMATOME_10118194-0001LF
JP1: ADC_CURR; 1X02
JP2: SWITCH_PINS; 1X05
JP4: UTILITY2; 1X08
L1: 1K@1MHz; R0805
R1, R2, R6, R12, R17, R19: 10k; R0805
R3: 4R7; R0805
R4, R5, R7, R11: 100k; R0805
R8: 187k; R0805
R9: 51k; R0805
R10: 1k; R0805
R13: 1M; R0805
R14, R15, R20: 49.9; R0805
R16, R18: 20k; R0805
U1: MAX4239ASA; 21-0041B_8
U2: TS5A23167DCUR; SOP50P310X90-8N
U3, U4: TS5A23166DCUR; SOP50P310X90-8N
U5: LTC6241CS8PBF; SOIC127P600X175-8N
U6: LTC6240CS8PBF; SO-8_S
X1: PN87520-S

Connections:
+5V: C2.+, JP4.8, L1.1, U1.7 (VCC), U2.8 (V+), U3.8 (V+), U4.8 (V+), U5.8 (V+), U6.7 (V+)
+5V_USB: J1.1 (VDD), L1.2
ADC_CURRENTHIGH: JP1.2, R15.1
ADC_CURRENTLOW: JP1.1, R14.1
ADC__VOLT: JP4.1, R20.2
D+: J1.3 (D+), X1.3
D-: J1.2 (D-), X1.2
DGND: D1.A, D2.C, J1.5 (GND), X1.4, X1.S1, X1.S2
GND: C1.-, D1.C, D2.A, JP4.3, JP4.5, R4.1, R6.2, R7.2, R10.1, R11.1, R12.1, R13.1, R17.1, R18.1, U1.4 (GND), U2.4 (GND), U3.4 (GND), U4.4 (GND), U5.4 (V-), U6.4 (V-)
unnamed: R16.1, R17.2, U6.3 (+IN)
unnamed: C8.1, R19.2, R20.1, U6.6 (OUT)
unnamed: C8.2, R18.2, R19.1, U6.2 (-IN)
unnamed: C5.1, R8.1, R14.2, U5.1 (OUT_A)
unnamed: C2.-, U1.1 (*SHDN)
unnamed: C3.2, R2.1, R5.2, U1.2 (IN-)
unnamed: C6.1, R9.1, R15.2, U5.7 (OUT_B)
unnamed: R1.1, R4.2, U1.3 (IN+)
unnamed: C5.2, R6.1, R8.2, U5.2 (-IN_A)
unnamed: C6.2, R7.1, R9.2, U5.6 (-IN_B)
OUT_STAGE1: C3.1, JP4.4, R5.1, U1.6 (OUT), U5.3 (+IN_A), U5.5 (+IN_B)
SW3_CON: R12.2, U3.1 (NO1)
SW4_CON: R10.2, U3.5 (NO2)
SW5_CON: R13.2, U4.1 (NO1)
SW6_CON: R11.2, U4.5 (NO2)
SWITCH_CTRL_2: JP2.1, U2.3 (IN2)
SWITCH_CTRL_3: JP2.2, U3.7 (IN1)
SWITCH_CTRL_4: JP2.3, U3.3 (IN2)
SWITCH_CTRL_5: JP2.4, U4.7 (IN1)
SWITCH_CTRL_6: JP2.5, U4.3 (IN2)
VBAT: C1.+, JP4.7, R1.2, R3.2, R16.2
VMCU: JP4.2, U2.1 (NC1), X1.1
VS-: JP4.6, R2.2, R3.1, U2.2 (COM1), U3.2 (COM1), U3.6 (COM2), U4.2 (COM1), U4.6 (COM2)

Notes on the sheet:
ADC VOLT AMPLIFIER
CALIBRATION SET
MAIN SWITCHING
FIRST STAGE
SECOND STAGE
RSHUNT
SUPPLY USB
MICRO USB
UTILITY PINS
GROUND STABILITY

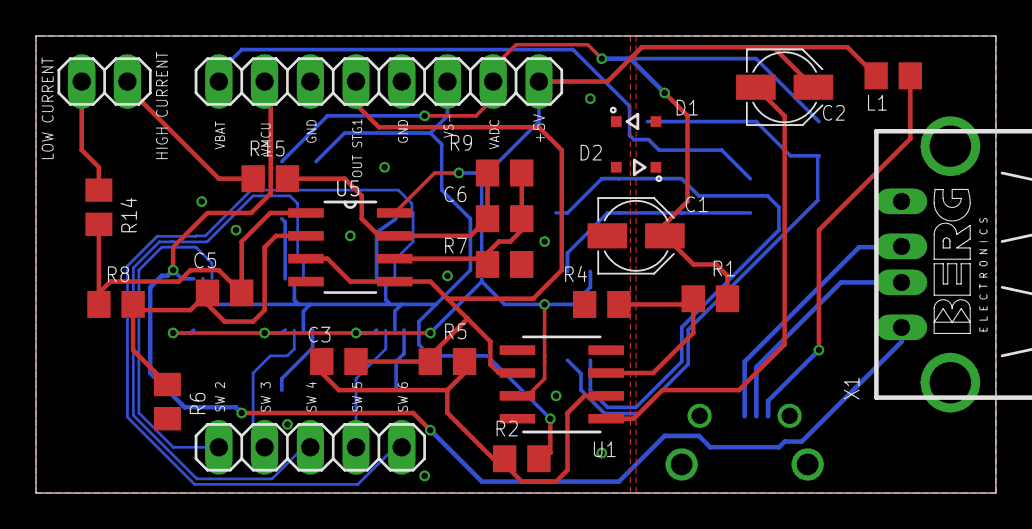
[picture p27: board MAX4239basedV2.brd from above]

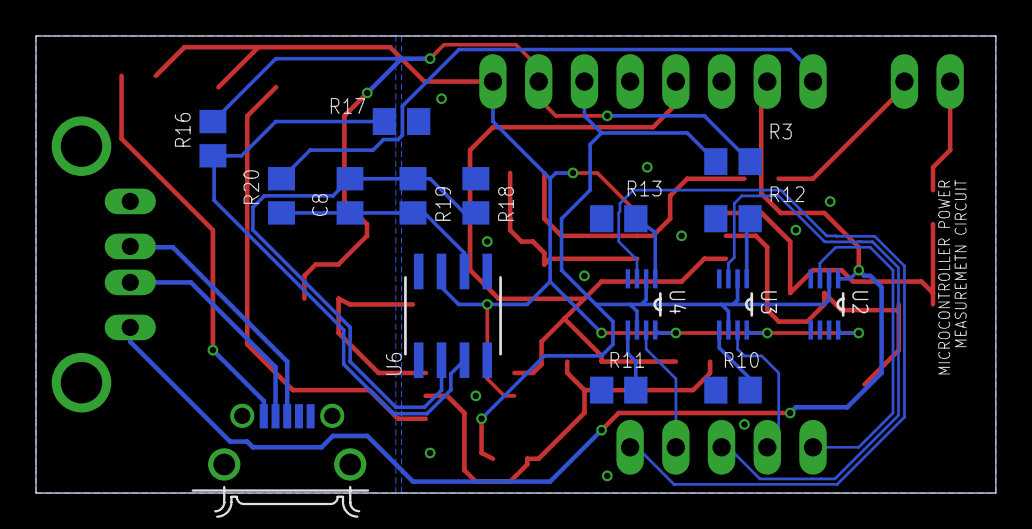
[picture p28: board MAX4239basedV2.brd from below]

Board: 2 copper layers, 53.3 x 25.4 mm, 40 parts (16 on the bottom side), 32 nets.

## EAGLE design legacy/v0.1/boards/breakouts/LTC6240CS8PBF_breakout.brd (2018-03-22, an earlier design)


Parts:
JP1, JP2: PINHD-1X4; 1X04
U1: LTC6240CS8PBF; SO-8_S

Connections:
GND: JP1.1, U1.4 (V-)
IN+: JP1.2, U1.3 (+IN)
IN-: JP1.3, U1.2 (-IN)
NC1: JP2.1, U1.8 (NC)
NC2: JP1.4, U1.1 (NC_2)
NC3: JP2.4, U1.5 (NC_3)
OUT: JP2.3, U1.6 (OUT)
VCC: JP2.2, U1.7 (V+)


Board: 2 copper layers, 20.3 x 12.7 mm, 3 parts (0 on the bottom side), 8 nets.

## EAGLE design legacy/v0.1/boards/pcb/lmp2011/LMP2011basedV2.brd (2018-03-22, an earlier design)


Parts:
C1: 1u; PANASONIC_B
C2, C3, C4, C5: 10p; C0805
D1, D2: CUS08F30; SOD323
J1: 10118194-0001LF; FRAMATOME_10118194-0001LF
JP1: ADC_CURR; 1X02
JP2: SWITCH_PINS; 1X05
JP3: UTILITY1; 1X08
R1, R6, R11, R27: 1k; R0805
R2, R13, R18, R21: 10k; R0805
R3: 4R7; R0805
R4, R5, R7, R10, R20, R22, R23, R24, R25: 100k; R0805
R8: 187k; R0805
R9: 51k; R0805
R12: 1M; R0805
R14, R15: 49.9; R0805
R16, R19: 20k; R0805
R17: 1K@1MHz; R0805
R26: 49.9; R0603
U1: TS5A23167DCUR; SOP50P310X90-8N
U2: LMP2011MF; SOT95P285X120-5N
U3, U4: TS5A23166DCUR; SOP50P310X90-8N
U5: LTC6241CS8PBF; SOIC127P600X175-8N
U6: LTC6240CS8PBF; SO-8_S
X1: PN87520-S

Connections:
+5V: JP3.8, R17.1, U1.8 (V+), U2.5 (V+), U3.8 (V+), U4.8 (V+), U5.8 (V+), U6.7 (V+)
+5V_USB: J1.1 (VDD), R17.2
ADC_CURRENTHIGH: JP1.2, R15.1
ADC_CURRENTLOW: JP1.1, R14.1
ADC__VOLT: JP3.3, R26.2
D+: J1.3 (D+), X1.3
D-: J1.2 (D-), X1.2
DGND: D1.A, D2.C, J1.5 (GND), X1.4, X1.S1, X1.S2
GND: C1.-, D1.C, D2.A, JP3.1, JP3.5, R4.1, R6.2, R7.2, R10.1, R11.1, R12.1, R13.1, R18.1, R19.1, R20.1, R22.1, R23.1, R24.1, R25.1, R27.2, U1.4 (GND), U2.2 (V-), U3.4 (GND), U4.4 (GND), U5.4 (V-), U6.4 (V-)
unnamed: R16.1, R18.2, U6.3 (+IN)
unnamed: C5.1, R21.2, R26.1, U6.6 (OUT)
unnamed: C5.2, R19.2, R21.1, U6.2 (-IN)
unnamed: C3.1, R8.1, R14.2, U5.1 (OUT_A)
unnamed: C2.2, R2.1, R5.2, U2.4 (VIN-)
unnamed: C4.1, R9.1, R15.2, U5.7 (OUT_B)
unnamed: R1.1, R4.2, U2.3 (VIN+)
unnamed: C3.2, R6.1, R8.2, U5.2 (-IN_A)
unnamed: C4.2, R7.1, R9.2, U5.6 (-IN_B)
OUT_STAGE1: C2.1, JP3.4, R5.1, R27.1, U2.1 (VOUT), U5.3 (+IN_A), U5.5 (+IN_B)
SW3_CON: R12.2, U3.1 (NO1)
SW4_CON: R10.2, U3.5 (NO2)
SW5_CON: R13.2, U4.1 (NO1)
SW6_CON: R11.2, U4.5 (NO2)
SWITCH_CTRL_1: JP2.1, R20.2, U1.3 (IN2), U1.7 (IN1)
SWITCH_CTRL_2: JP2.2, R22.2, U3.7 (IN1)
SWITCH_CTRL_3: JP2.3, R23.2, U3.3 (IN2)
SWITCH_CTRL_4: JP2.4, R24.2, U4.7 (IN1)
SWITCH_CTRL_5: JP2.5, R25.2, U4.3 (IN2)
VBAT: C1.+, JP3.7, R1.2, R3.2, R16.2
VMCU: JP3.2, U1.1 (NC1), U1.5 (NC2), X1.1
VS-: JP3.6, R2.2, R3.1, U1.2 (COM1), U1.6 (COM2), U3.2 (COM1), U3.6 (COM2), U4.2 (COM1), U4.6 (COM2)

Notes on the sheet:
ADC AMPLIFIER
CALIBRATION SET
MAIN SWITCHING
FIRST STAGE
SECOND STAGE
RSHUNT
SUPPLY USB
MICRO USB
GROUND PLANE MAX DC LIMITATION
X188 GAIN
X1.51 GAIN
X.5 GAIN



Board: 2 copper layers, 53.4 x 25.4 mm, 45 parts (17 on the bottom side), 31 nets.

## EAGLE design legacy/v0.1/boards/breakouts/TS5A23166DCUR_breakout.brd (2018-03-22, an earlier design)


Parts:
JP1, JP2: PINHD-1X4; 1X04
U1: TS5A23166DCUR; SOP50P310X90-8N

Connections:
COM1: JP2.2, U1.2 (COM1)
COM2: JP1.2, U1.6 (COM2)
GND: JP2.4, U1.4 (GND)
IN1: JP1.3, U1.7 (IN1)
IN2: JP2.3, U1.3 (IN2)
NO1: JP2.1, U1.1 (NO1)
NO2: JP1.1, U1.5 (NO2)
VCC: JP1.4, U1.8 (V+)


Board: 2 copper layers, 15.2 x 12.7 mm, 3 parts (0 on the bottom side), 8 nets.

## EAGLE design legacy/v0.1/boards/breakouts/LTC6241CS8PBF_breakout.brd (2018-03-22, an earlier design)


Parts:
JP1, JP2: PINHD-1X4; 1X04
U1: LTC6241CS8PBF; SOIC127P600X175-8N

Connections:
+IN_A: JP1.3, U1.3 (+IN_A)
+IN_B: JP2.1, U1.5 (+IN_B)
-IN_A: JP1.2, U1.2 (-IN_A)
-IN_B: JP2.2, U1.6 (-IN_B)
GND: JP1.4, U1.4 (V-)
OUT_A: JP1.1, U1.1 (OUT_A)
OUT_B: JP2.3, U1.7 (OUT_B)
V+: JP2.4, U1.8 (V+)


Board: 2 copper layers, 20.3 x 12.7 mm, 3 parts (0 on the bottom side), 8 nets.

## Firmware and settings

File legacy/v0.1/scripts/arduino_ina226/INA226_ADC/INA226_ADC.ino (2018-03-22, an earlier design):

/*
    INA226 Bi-directional Current/Power Monitor. Simple Example.
    Read more: http://www.jarzebski.pl/arduino/czujniki-i-sensory/cyfrowy-czujnik-pradu-mocy-ina226.html
    GIT: https://github.com/jarzebski/Arduino-INA226
    Web: http://www.jarzebski.pl
    (c) 2014 by Korneliusz Jarzebski
*/

#include <Wire.h>
#include "INA226.h"

INA226 ina;

void checkConfig()
{
  Serial.print("Mode:                  ");
  switch (ina.getMode())
  {
    case INA226_MODE_POWER_DOWN:      Serial.println("Power-Down"); break;
    case INA226_MODE_SHUNT_TRIG:      Serial.println("Shunt Voltage, Triggered"); break;
    case INA226_MODE_BUS_TRIG:        Serial.println("Bus Voltage, Triggered"); break;
    case INA226_MODE_SHUNT_BUS_TRIG:  Serial.println("Shunt and Bus, Triggered"); break;
    case INA226_MODE_ADC_OFF:         Serial.println("ADC Off"); break;
    case INA226_MODE_SHUNT_CONT:      Serial.println("Shunt Voltage, Continuous"); break;
    case INA226_MODE_BUS_CONT:        Serial.println("Bus Voltage, Continuous"); break;
    case INA226_MODE_SHUNT_BUS_CONT:  Serial.println("Shunt and Bus, Continuous"); break;
    default: Serial.println("unknown");
  }
  
  Serial.print("Samples average:       ");
  switch (ina.getAverages())
  {
    case INA226_AVERAGES_1:           Serial.println("1 sample"); break;
    case INA226_AVERAGES_4:           Serial.println("4 samples"); break;
    case INA226_AVERAGES_16:          Serial.println("16 samples"); break;
    case INA226_AVERAGES_64:          Serial.println("64 samples"); break;
    case INA226_AVERAGES_128:         Serial.println("128 samples"); break;
    case INA226_AVERAGES_256:         Serial.println("256 samples"); break;
    case INA226_AVERAGES_512:         Serial.println("512 samples"); break;
    case INA226_AVERAGES_1024:        Serial.println("1024 samples"); break;
    default: Serial.println("unknown");
  }

  Serial.print("Bus conversion time:   ");
  switch (ina.getBusConversionTime())
  {
    case INA226_BUS_CONV_TIME_140US:  Serial.println("140uS"); break;
    case INA226_BUS_CONV_TIME_204US:  Serial.println("204uS"); break;
    case INA226_BUS_CONV_TIME_332US:  Serial.println("332uS"); break;
    case INA226_BUS_CONV_TIME_588US:  Serial.println("558uS"); break;
    case INA226_BUS_CONV_TIME_1100US: Serial.println("1.100ms"); break;
    case INA226_BUS_CONV_TIME_2116US: Serial.println("2.116ms"); break;
    case INA226_BUS_CONV_TIME_4156US: Serial.println("4.156ms"); break;
    case INA226_BUS_CONV_TIME_8244US: Serial.println("8.244ms"); break;
    default: Serial.println("unknown");
  }

  Serial.print("Shunt conversion time: ");
  switch (ina.getShuntConversionTime())
  {
    case INA226_SHUNT_CONV_TIME_140US:  Serial.println("140uS"); break;
    case INA226_SHUNT_CONV_TIME_204US:  Serial.println("204uS"); break;
    case INA226_SHUNT_CONV_TIME_332US:  Serial.println("332uS"); break;
    case INA226_SHUNT_CONV_TIME_588US:  Serial.println("558uS"); break;
    case INA226_SHUNT_CONV_TIME_1100US: Serial.println("1.100ms"); break;
    case INA226_SHUNT_CONV_TIME_2116US: Serial.println("2.116ms"); break;
    case INA226_SHUNT_CONV_TIME_4156US: Serial.println("4.156ms"); break;
    case INA226_SHUNT_CONV_TIME_8244US: Serial.println("8.244ms"); break;
    default: Serial.println("unknown");
  }
  
  Serial.print("Max possible current:  ");
  Serial.print(ina.getMaxPossibleCurrent());
  Serial.println(" A");

  Serial.print("Max current:           ");
  Serial.print(ina.getMaxCurrent());
  Serial.println(" A");

  Serial.print("Max shunt voltage:     ");
  Serial.print(ina.getMaxShuntVoltage());
  Serial.println(" V");

  Serial.print("Max power:             ");
  Serial.print(ina.getMaxPower());
  Serial.println(" W");
}

void setup() 
{
  Serial.begin(115200);

  Serial.println("Initialize INA226");
  Serial.println("-----------------------------------------------");

  // Default INA226 address is 0x40
  ina.begin();

  // Configure INA226
  ina.configure(INA226_AVERAGES_4, INA226_BUS_CONV_TIME_1100US, INA226_SHUNT_CONV_TIME_140US, INA226_MODE_SHUNT_BUS_CONT);

  // Calibrate INA226. Rshunt = 0.01 ohm, Max excepted current = 4A
  ina.calibrate(1.5, 0.05);

  // Display configuration
  checkConfig();

  Serial.println("-----------------------------------------------");
}

void loop()
{
  Serial.print("Bus voltage:   ");
  Serial.print(ina.readBusVoltage(), 5);
  Serial.println(" V");

  Serial.print("Bus power:     ");
  Serial.print(ina.readBusPower(), 5);
  Serial.println(" W");


  Serial.print("Shunt voltage: ");
  Serial.print(ina.readShuntVoltage(), 5);
  Serial.println(" V");

  Serial.print("Shunt current: ");
  Serial.print(ina.readShuntCurrent(), 5);
  Serial.println(" A");

  Serial.println("");
  delay(1000);
}

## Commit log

2018-02-14 add calibrate func
2018-03-15 fix error in adc resolution setting function
    [measure.c]
2018-03-22 move first iteration to v0.1 folder
    [LMP2011basedV1.brd, LMP2011basedV1.sch, LMP2011basedV2.brd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]
2018-03-26 add base spice design for ada4522 base circuit
2018-03-28 update schematics
2018-03-28 initial work on pcb eagle
    [Eagle.sch]
2018-04-05 first circuit for AD8629
2018-04-09 add AD8422 for large current measurement - change power supply
2018-04-09 fix power supply for ad8629
2018-04-10 pcb: add eagle symbols
    [Eagle.sch]
2018-04-10 boards: add initial version for ltc6102 based board
    [cm_ltc6102.brd, cm_ltc6102.sch]
2018-04-11 cm_ltc6102: add dgnd and agnd connection, fix silk-screen
    [cm_ltc6102.brd, cm_ltc6102.sch]
2018-04-13 fix some missing gnd wires
    [cm_ltc6102.brd, cm_ltc6102.sch]
2018-04-13 add larger version of ltc6102 based board
    same ics different board size
    [cm_ltc6102.brd, cm_ltc6102.sch]
2018-04-13 create measure-circuit to eagle sch
    [cm_AD8629.sch]
2018-04-16 cm_ltc6102_L: modify layout, finish silkscreen
    [cm_ltc6102.brd, cm_ltc6102.sch]
2018-04-16 cm_ltc6102_L: fix wrong sized ic and surface capacitor
    [cm_ltc6102.brd, cm_ltc6102.sch]
2018-04-16 add bom
    [bom.csv]
2018-04-17 add analog switch eagle symbol
    [Eagle.sch]
2018-04-17 add 12v boost to sch
    [cm_AD8629.sch]
2018-04-17 add 12v boost power supply
2018-04-18 add regulator and boost
    [cm_AD8629.sch]
2018-04-18 add usb entry
    [cm_AD8629.sch]
2018-04-18 fix enable pull ups error, update bom
    [bom.csv, cm_ltc6102.brd, cm_ltc6102.sch]
2018-04-20 add layout board
    [cm_AD8629.brd]
2018-04-20 add boom file
    [cm_AD8629-boom.csv]
2018-04-20 fix issues
    [cm_AD8629.sch]
2018-04-20 first version of layout
    add bom file
    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
    [cm_AD8629-boom.csv, cm_AD8629.brd, cm_AD8629.sch]
2018-04-20 add usb ports to schematics
    [cm_AD8629.brd, cm_AD8629.sch]
2018-04-20 cm_ltc6102: increase track size add doc
    [bom.csv, cm_ltc6102.brd, cm_ltc6102.sch]
2018-04-23 change AD8629 to ADA4522
    [cm_AD8629.brd, cm_ADA4522.brd, cm_ADA4522.sch]
2018-04-23 ltc6102_board: change silscreen names to top silkscreen
    [cm_ltc6102.brd]
2018-04-23 ltc6102_board: minor board fixes
    [cm_ltc6102.brd]
2018-04-23 connect data ports from usb
    [cm_ADA4522.brd, cm_ADA4522.sch]
2018-04-23 add bom to folder
    [cm_AD8629-boom.csv, cm_ADA4522.csv]
2018-04-23 add names to external connectors
    [cm_ADA4522.brd, cm_ADA4522.sch]
2018-05-02 move v0.2 files to common folder
    [cm_ADA4522.brd, cm_ADA4522.csv, cm_ADA4522.sch]
2018-05-02 update common board readme
2018-05-02 add ltc6102 bom
    [cm_ltc6102.csv]
2018-05-02 update bom for ada4522
    [cm_ADA4522.csv]
2018-05-23 update board readme
2018-06-15 add schematic file as pdf
2018-06-15 add schematic pdf file to ada board
2018-08-27 Add version 3 of hardware: include control node and usb bridge in design
    [bom_exported.csv]
2018-10-09 Fix bugs v0.3
    [bom_exported.csv]
2018-10-17 change R14 Digikey Part Number to 0805 footprint
    [bom_exported.csv]
2018-12-18 Readme: Add connectors information and pinout
2019-06-05 Relocate hardware files
    [Eagle.sch, LMP2011basedV1.brd, LMP2011basedV1.sch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]

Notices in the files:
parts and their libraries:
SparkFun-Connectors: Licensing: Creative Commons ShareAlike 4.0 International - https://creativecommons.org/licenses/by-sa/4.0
